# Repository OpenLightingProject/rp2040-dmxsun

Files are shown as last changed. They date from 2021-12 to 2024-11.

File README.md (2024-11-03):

# rp2040-dmxsun: A USB-DMX device based on RaspberryPi's RP2040 micro-controller with modular hardware

<p align="center">

</p>

## What is it?

The rp2040-dmxsun is a multi-purpose DMX-512-A toolbox to control stage lighting systems. It's most common use-case is to transmit the DMX data generated on a PC, Raspberry Pi or similar in a format that the lighting fixtures on stage can understand. In the most simple case, it's an USB-DMX interface.

DMX-512-A works in networks called universes and each universe can contain up to 512 slots of data. dmxsun can transmit up to 16 universes, meaning you can control 8192 slots of DMX data at the same time.

Dmxsun is usually connected to its host via a single USB connection that also powers the device.
To the computer, the dmxsun device looks like a network card (it uses the CDC NCM interface) and the integrated DHCP-server assigns an IP-address to the host machine so they can talk to each other.

To find out dmxsun's IP address, have a look at your kernel log on Linux (run `dmesg`) or hover over the `Disconnect USB device` icon in Window's task bar or check the network device properties on macOS.

You can browse to this IP address in your web browser to access the integrated web server or you can send ArtNet or E1.31/sACN packets to the IP address to make dmxsun send this data as DMX data.

Furthermore, you can attach an nRF24 radio module to the base board to send or receive up to 4 universes wirelessly to or from another dmxsun device. That also means that the device can also work stand-alone, receiving DMX data from another dmxsun device and outputting it on local ports.

## Why is it called dmxsun?

The idea came when thinking about a suitable icon for the pages on the integrated web server. You can think about the dmxsun as being a central device and 16 rays of light coming out of it.

**Sun** could also be seen as an acronym for **s**ixteen **un**iverses :D

Maybe it's also because outdoor lighting technicians absolutely love the sun since they can perfectly set up their light show while the sun is shining bright ;)

## What does it look like?

The hardware consists of a base board into which the Raspberry Pi Pico-board plugs in to. To get a quick overview of the board's status, 8 RGB status LEDs are attached to the base board.

3D rendering of the base board without the Pico board plugged in

Attached to this base board can be 0 to 4 IO boards that carry the actual RS-485 drivers and XLR connectors:

3D rendering of an IO board without the XLR connectors

If all 4 IO boards are attached to the base board, you can have 16 output ports fitting into 1U of an 19" rack:

3D rendering of base board + 4 IO boards

## How is configuration data handled?

The complete configuration of the device, including IP address, patching and wireless configuration can be stored on any of the IO boards or on the base board.

When the device powers up, it scans the 4 IO board slots in order for connected boards and the configuration stored on them. As soon as a valid and non-disabled configuration is found, it is loaded and used. If no IO board has a valid configuration, it tries to load the config from the flash memory of the Pico board. If this also doesn't seem valid, a fallback configuration is applied.

The status LEDs on the base board indicate which IO boards have a valid configuration and which configuration is currently active.

All the configurations can be managed via the integrated web server.

## Where can I buy it?

Short answer: You can't. There is not (yet) a ready-made piece of hardware that can be bought and is ready to use. However, you are invited to build your own. Read on ;)

Longer answer: JLCPCB or a similar PCB factory. The schematics and PCB layout files are in the `hardware` folder (KiCad format) and you can send them to any PCB fab to have it produced for you. Then it's a bit of soldering on your side, plugging in a RaspberryPi Pico board and you're good to go.

If you just want to have a brief look at the schematics without cloning the repo and opening the files in KiCad, take a look at the kicad-export action: https://github.com/OpenLightingProject/rp2040-dmxsun/actions/workflows/kicad-exports.yml. It will generate a zip-archive containing all sort of PDFs.

**!!! Upcoming, incompatible hardware change: In the current schematics, we are using 256 byte large I2C-EEPROMs to store personality and configuration data. With the release of the Pico W and the need to store WiFi SSIDs and passwords, this will no longer be enough and the EEPROMs should provide 4096 byte in the future !!!**

## How can I try it out without spending much?

Very good question! All you need is a RaspberryPi Pico board, a microUSB cable and a PC, Laptop or RaspberryPi. You won't be able to actually control lighting fixtures, but you can get an idea of how this project works.

* Download the latest `UF2`-file (for example from here: https://github.com/OpenLightingProject/rp2040-dmxsun/actions/workflows/pico-build.yml) and flash it to your Pico board (see above)
* Wait until the board has rebooted and your PC has finished setting up the emulated network connection
* Find out the dmxsun's IP address as described in the [What is it?](#what-is-it)-section
* Open your web browser, browse to the IP address. You should see a web page with status information
* Using the navigation bar at the top, browse to `Console` and start changing values. Or fire up your favourite lighting control software (such as OLA or QLC+), configure it to send ArtNet or E1.31/sACN to the dmxsun's IP address and watch the values change in your web browser. It might seem laggy but that's only because the web interface only updates every second.
* If you're curious and have such devices, connect a logic analyzer or RS-485 driver to GPIOs 6 to 21. Those are the pins where the DMX data comes out. If you attach an RS-485-driver to one of those, you can also attach and control real fixtures.

## How do I compile the firmware?

If you just want to get started quickly find the most recent action run from the branch you're interested in, extract the attached artifact zip file (from https://github.com/OpenLightingProject/rp2040-dmxsun/actions/workflows/pico-build.yml ) and copy the rp2040-dmxsun.uf2 file to the Pico board when it's in bootloader mode.

Since this is a project that adheres to the guidelines set by Raspberry Pi for its pico-sdk (hopefully), you are best off following the detailed documentation at https://datasheets.raspberrypi.com/pico/getting-started-with-pico.pdf.

The build process will also build the React App for the integrated Web UI. For this to work, you will need to have NodeJS 14+ and NPM installed. React and all other JavaScript dependencies will be downloaded during the build, so make sure you are connected to the Internet.

With all dependencies installed, the following steps should suffice (example is for Linux, might differ for other OS):
```
git clone --recursive https://github.com/OpenLightingProject/rp2040-dmxsun.git
cd rp2040-dmxsun
mkdir build
cd build
cmake ..
make -j$(($(nproc)+1))
```
This should result in an `.uf2`-file being generated that you can flash to your Pico-board as described in Raspberry Pi's documentation.

**If you are seeing build errors, please make sure you are using pcio-sdk v1.5.0 (released 2023-02-11)**

## How does the data flow internally?

Dmxsun uses a pretty flexible architecture, consisting of mainly 24 DMX buffers acting as the main data storage. Data can come in via USB (either via the emulated Ethernet or some other, emulated protocol), wirelessly via the nRF24 module or from one input port and is then, depending on "patching" stored in one or more DMX buffers.

From there, again depending on "patching", the data is sent to one or more of the local DMX ports, to the nRF24 wireless module or to the host PC via Art-Net or E1.31/sACN.

The patching is currently fixed but will be made fully configurable in the future. The current patching works like this: Universes 1-16 from USB or emulated Ethernet go to internal DMX buffers 1-16 which go to the 16 local DMX ports. Additionally, the first 4 universes are also broadcast via the nRF24 module, should one be connected. Data coming in via the wireless module is sent to DMX buffers 5-8 and will as such appear on the local DMX ports 5-8.

## What are the upcoming features?

The best overview of planned features is to have a look at the GitHub issues: https://github.com/OpenLightingProject/rp2040-dmxsun/issues.

Since the hardware is modular, we do have the option to also support DMX input (currently work-in-progress) or universes with RDM support. There would also be the possibility to drive up to 6 WS2812b-based LED-strings instead of conventional DMX-512-A right off the board.

For the wireless part, mesh support is planned so you can add additional nodes forwarding the data when the wireless range is insufficient. It would also be great if we could talk to other, existing wireless DMX systems.

What might also help to make it easier to use is if dmxsun could emulate other, existing, USB DMX dongles. Then, it could also be used with other software that is not able to send Art-Net or E1.31/sACN but supports other dongles. The disadvantage here is that only a few dongles support more than 4 universes, while dmxsun supports 16.

As said above, the internal patching is hardcoded and cannot be changed by the user. This will change in the future, so that the current patching can be seen and changed in the integrated web interface.

## How is the project licensed?

This source code, schematics and board layouts is licensed under the Apache-2.0 license.

Parts of the original example code (`stdio_usb.*`, ...) is:

     * Copyright (c) 2020 Raspberry Pi (Trading) Ltd.
     * SPDX-License-Identifier: BSD-3-Clause

Parts taken and modified from TinyUSB (`tusb_config.h`, `usb_descriptors.c`) is:

     * The MIT License (MIT)
     * Copyright (c) 2019 Ha Thach (tinyusb.org)

This project proudly uses the following libraries and thanks the respective developers for their amazing work:
* [jsoncpp](https://github.com/open-source-parsers/jsoncpp), MIT license
* [libb64](https://github.com/libb64/libb64), Public domain
* [lwIP](https://savannah.nongnu.org/projects/lwip/), Modified BSD License
* [Pico-DMX](https://github.com/jostlowe/Pico-DMX), BSD 3-Clause "New" or "Revised" License
* [RF24, RF24Network and RF24Mesh](https://github.com/nRF24/RF24), GPL-2.0. Since this is not compatible with our Apache-2.0 license, this dependency will be removed in the future. dmxsun was GPL-licensed in the past
* [snappy](https://github.com/google/snappy), The 3-Clause BSD License

And for the integrated Web UI:
* [React](https://reactjs.org/), MIT license
* [Bootstrap](https://getbootstrap.com/), MIT license
* [Chart.js](https://www.chartjs.org/), MIT license
* [couch64](https://www.npmjs.com/package/couch64), CC-BY-SA
* [snappyjs](https://github.com/zhipeng-jia/snappyjs), MIT license
* [react-input-slider](https://github.com/swiftcarrot/react-input-slider), MIT license

## What else do I need to know?

If you attach an nRF24-board, you yourself are responsible to make sure you don't violate any local laws or regulations. Not all channels and transmit powers that the nRF24 module can use may be allowed to be used in your area. The Open Lighting Project cannot be held responsible should you break the law by using this project's hardware and/or software. Also, we did not run any EMC tests on the hardware. It might not be legal to operate the board without FCC, CE or similar certification, depending on where you live.

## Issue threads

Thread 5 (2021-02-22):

Implement automatic binary generation using GitHub Actions

kripton, 2021-02-22:
The binaries for the Pico board should easily be generated by some kind of CI pipeline

peternewman, 2021-02-22:
Happy to help with this as I've done various similar bits in Actions but doing a GitHub Pages thing to publish may be easier (as the actions artefacts expire after a while and only appear as zips).

I'm assuming RPF have some pretty good docs on it, I guess someone might have made an Action already!

kripton, 2021-02-23:
I am new to GitHub Actions and I was honestly curious to try them out finally :) Didn't find anything on the marketplace and also a quick internet research didn't bring up anything meaningful. Thus, I decided to base off the `cmake` pipeline, add the required steps to set up the Pico toolchain and SDK and off it goes :)
I completely agree that gh-pages might be preferable and now we do have a prebuilt binary in the `bin` folder and the ones generated by Actions from the source. Don't know what's easier for users to find.

peternewman, 2021-02-23:
> I am new to GitHub Actions and I was honestly curious to try them out finally :)

You beat me to it! I got as far as opening a new file on my lunch break then got distracted.

> I completely agree that gh-pages might be preferable and now we do have a prebuilt binary in the `bin` folder and the ones generated by Actions from the source. Don't know what's easier for users to find.

My example may not be hugely helpful as it's somewhat niche, but this uses GH pages (in this case to host a deb):
https://github.com/peternewman/Date-Holidays-GB/compare/actions...peternewman:actions-gh-pages-apt

If you're happy to have the noise in your repo, branches are really easy, there's a commit action. You could link to gh-pages from the readme.

Things to consider:
branch builds - do-able with pages, would just need a bit of thought as to how they're listed to make multiple ones available
PR builds - probably want to be actions only
I think commit scope would be similar in both cases.

Closed 2021-02-23.

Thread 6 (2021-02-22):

Implement a "switch to bootloader" command

kripton, 2021-02-22:
When flashing the Pico over USB (instead of using the SWD-based debug port and OpenOCD), one needs to replug the board everytime it should be flashed. If fhe SDK allows it, add a command to the USB protocol to reboot to the bootloader.

2bndy5, 2021-04-03:
just passing this along:

>If fhe SDK allows it, add a command to the USB protocol to reboot to the bootloader.

It would seem that it does support this. I haven't found any example yet, but I found [_**this macro**_](https://github.com/raspberrypi/pico-sdk/blob/1769968c426555454ab88917115abcb96bcfd1cd/src/rp2_common/pico_stdio_usb/include/pico/stdio_usb.h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) in search of how to redirect UART I/O to USB (or vice versa). I imagine that using this defined baudrate is how the [unofficial ArduinoCore-pico](https://github.com/earlephilhower/arduino-pico) is automatically resetting the board when re-programming the pico (or other RP2040 based boards).

There's also [this library](https://datasheets.raspberrypi.org/pico/raspberry-pi-pico-c-sdk.pdf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) which seems like it would be commonly used by CircuitPython/MicroPython firmware to let the user reset-to-bootloader when the reset button is double clicked.

kripton, 2021-04-20:
Fixed with https://github.com/OpenLightingProject/rp2040-dongle/commit/dd2dc2cf51eed4e9961ec046b7b0a472e5cc146c
@2bndy5: This seems to be some kind of "official" way to do it. It can be enabled in the pico-sdk by adding some #defines to a project, assume it's using the stdio_usb interface. See https://github.com/raspberrypi/pico-sdk/commit/383e88ea165bc63e5755e042608bbc1164e75ab7

kripton, 2022-01-08:
Reboot-to-Bootloader is now also available via the HTTP API (integrated webserver):
https://github.com/OpenLightingProject/rp2040-dongle/blob/79556f4ebf31f9bb41bdc5a23bae965987fad62d/src/webserver.cpp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

Closed 2021-04-20.

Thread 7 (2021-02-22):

Serial Numbers/UIDs

peternewman, 2021-02-22:
I see you've already mentioned this partly in https://github.com/OpenLightingProject/rp2040-dongle/discussions/2 but given it's important we don't get UID clashes in our space so for now if you're using static ones it would be good to switch to some of the reserved ones here (any of the development blocks are fine):
https://wiki.openlighting.org/index.php/Open_Lighting_Allocations#UIDs

What serial(s)/MAC(s) does the RP2040 chip ship with and I can suggest some ways we could make use of them based on what we've done in the past.

kripton, 2021-02-23:
You're right, for now this should be using development IDs.
The RP2040-chip itself has no unique identifier at all. According to RasbperryPi, they are all identical (except tolerances and thus timing differences). However, each Pico board comes with a Flash chip that has a unique identifier (64 bit long). As such, we cannot know if it might clash with the way serial numbers are generated on other boards that use means to generate their serial number.
Sadly, when shorting that flash-unique-id, it's no longer guaranteed to be unique. I was not able to find if there is some kind of meaning to individual bits of the ID (like a common vendor-part).
This is how the unique ID is read from the flash in the pico-sdk: https://github.com/raspberrypi/pico-sdk/commit/620c75b9b85ca160d929a3a5df3c96a8d433f3be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

In the beginning (when the rp2040-dongle was emulating the Nodle U1 board), I had the complete unique ID as a serial number: https://github.com/OpenLightingProject/rp2040-dongle/blob/main/src/usb_descriptors.c#L160 (still current in main branch).
However, since the Ja Rule protocol mandates the PLASA format (which is not a bad thing), those can no longer be used. I've decided to use the last 4 byte of the board id for now: https://github.com/OpenLightingProject/rp2040-dongle/blob/JaRuleProto/src/usb_descriptors.c#L223, not being aware that the OLA-range was already organized that well!

I can't really think of a proper solution since no matter how we shorten, truncate or hash the 8 byte long unique id of the flash, the result will never be guaranteed to be unique, thus they are not safe to protect clashes reliably.

The only thing we could do is to reserve another range (7a70:40000000 - 7a70:4fffffff) and hope they never collide (it's still 28 bit of "randmon-ness", which should suffice in most cases).

peternewman, 2021-02-23:
> You're right, for now this should be using development IDs.

Thanks!

> I can't really think of a proper solution since no matter how we shorten, truncate or hash the 8 byte long unique id of the flash, the result will never be guaranteed to be unique, thus they are not safe to protect clashes reliably.

Agreed, I guess all we can really do is hope no-one is unlucky. OLE also allows a UID value from flash (e.g. for testing collisions or other purposes), so that could be a possible option if someone did have a clash.

> The only thing we could do is to reserve another range (7a70:40000000 - 7a70:4fffffff) and hope they never collide (it's still 28 bit of "randmon-ness", which should suffice in most cases).

For a bit of background see here for more detail of how the OLE UIDs are defined:
https://github.com/OpenLightingProject/ja-rule/blob/0e4bf7bd6e944222f1b64996c93c3ac87a607de5/common/uid_store.c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

If you're never planning to do dummy RDM responders, or responders dummying proxy devices, then you'd only need one UID per device, so could avoid the shift. Although it might be good to keep that an option unless memory space is likely to be too limiting.

I'll have a bit of a ponder, but keeping the potential Microchip OUIs and any future ones sequential and chucking this in at 7a70:e... feels like it might make sense.

peternewman, 2021-02-23:
Random lsusb serial:
E0C912D24340

I don't know if it gives much hint to the numbering, or if it's truly random?

kripton, 2021-02-23:
> > You're right, for now this should be using development IDs.
>
> Thanks!

Implemented in the JaRule-branch: https://github.com/OpenLightingProject/rp2040-dongle/blob/JaRuleProto/src/usb_descriptors.c#L183 and https://github.com/OpenLightingProject/rp2040-dongle/blob/JaRuleProto/src/usb_descriptors.c#L210

> Agreed, I guess all we can really do is hope no-one is unlucky. OLE also allows a UID value from flash (e.g. for testing collisions or other purposes), so that could be a possible option if someone did have a clash.

Yes. At least when I made it that far that I can read & write the flash. Currently, it's the bootloader loading the program and running it. Until now there was no point in storing persistent settings. But yes, I did see the `SET_SERIAL` command in the protocol and thought the same.

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

Indeed, that source code is a good reading. I was not aware that the JaRule devices can act as an RDM proxy and use those 4 bits for that. Nice idea :+1:
And regarding the range, I also had in mind that there should be some space after the current JaRule-ranges in case Microchip acquires more OIDs in the future. I'd be happy with the 7a70:e... range as well :)

kripton, 2021-02-23:
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

That's the one form the bootloader, right? I thought the same at first, however it's not what the both of us thought it was: https://github.com/raspberrypi/pico-examples/issues/6#issuecomment-768149841

What you are seeing there is some kind of revision number of the bootloader and is the same on all Pico boards ;) When the device is running in `BOOTSEL` mode (= bootloader), there is no unique identification feature :-/

peternewman, 2021-02-24:
> Indeed, that source code is a good reading. I was not aware that the JaRule devices can act as an RDM proxy and use those 4 bits for that. Nice idea
> And regarding the range, I also had in mind that there should be some space after the current JaRule-ranges in case Microchip acquires more OIDs in the future. I'd be happy with the 7a70:e... range as well :)

I suspect there's unfortunately not a huge amount of progress likely to be made with Microchip based JaRule stuff, but equally given this is almost pseudo-random UID allocation given the overflow it's probably still sense to split them up.

Are you interested in that level of flexibility in your device?

> That's the one form the bootloader, right? I thought the same at first, however it's not what the both of us thought it was: [raspberrypi/pico-examples#6 (comment)](https://github.com/raspberrypi/pico-examples/issues/6#issuecomment-768149841)

It was some random one off the Internet!

I guess if I load your main branch, I should see my serial there to compare.

kripton, 2021-02-25:
Regarding RDM proxy and the reserved bits, I'm totally unsure. I don't have any experience at all with RDM and cannot judge if the dongle should support that. Sure, with a good number of ports, it could be configured as RDM-capable splitter where this feature would come in handy.
On the other hand, it would increase the likelihood of an ID clash (28 bit of uniqueness vs. 24 bit). I don't have a definite answer but my gut feeling tends to go for 24 bit unique id + 4 "reserved" bits for the advanced RDM functionality. Probably won't hurt.

Indeed, if you flash the current `main` branch (the one emulating the Nodle U1 protocol), you should see the full 8 byte / 64 bit / 16 characters, truly unique serial number.

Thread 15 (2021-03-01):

Simplify Logging Code

peternewman, 2021-03-01:
You've currently got e.g.
https://github.com/OpenLightingProject/rp2040-dongle/blob/08e6e144c32b5bf002fd0e936cf510dbeb2a6162/src/jaruleproto.c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

In OLA we use `__FILE__` too, but we also setup a macro to centralise and tidy most of the back-end commands (although I guess the latter might be a bit harder if it's all in a printf):
https://github.com/OpenLightingProject/ola/blob/ea3a18a925f123c8771ebc6c60327678e99ddcf2/include/ola/Logging.h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

kripton, 2021-03-01:
Indeed, fully agree. That is meant to be a macro eventually. For the moment, it's just written to fulfil the needs.
I did try `__LINE__`, however it contains the full file path and that was a bit long for me. I saw some functions online that return only he filename but I didn't yet bother to integrate them.

peternewman, 2021-03-03:
> I did try `__LINE__`, however it contains the full file path and that was a bit long for me. I saw some functions online that return only he filename but I didn't yet bother to integrate them.

I assume you mean `__FILE__`? That's interesting, in OLA we just get the relative path (say `src/jaruleproto.c`).

kripton, 2021-03-03:
Indeed, I meant `__FILE__`. Maybe it depends on the build system used? It could be that OLA's GNU Make-based build system calls the compiler with relative paths while the CMake-based build system for Pico-projects calls the compiler with absolute paths?

kripton, 2021-03-04:
I played around a little with the logging code. Actually, rather for checking if C++ can be used on the RP2040. Result: Working, but some things (such as iterators) will lead to compile-time errors such as https://github.com/purduesigbots/pros/issues/134

Current status at https://github.com/OpenLightingProject/rp2040-dongle/tree/kripton-cppTest. Can be used as a base but I might rewrite that in plain C. Will see ;)

Closed 2021-12-22.

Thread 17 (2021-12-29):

Any harware refrance.

ScobbyDoo, 2021-12-29:
Hi,
Im looking for any schematic to make one & try
If you have schematic i wll design pcb & share it.

kripton, 2021-12-29:
Hi @ScobbyDoo and I'm happy that you want to try it.
The schematic and PCD design files are in the "hardware" branch: https://github.com/OpenLightingProject/rp2040-dongle/tree/hardware. The files are created using KiCad.
It's basically the baseboard + some baseboard options that you can connect to the base board. I have several ones here, ordered at JLCPCB.

Of course, you can also do a prototyping solution and simply hook up some RS-485-Driver breakout-boards to the RPi Pico board via jumper wires. The connections can be seen in the KiCad-schematics but don't hesitate to ask here if something is unclear.

Each IO board usually contains one I2C-EEPROM to give the base board some information about the IO board (available ports, port direction, .....) but at the moment, the firmware just assumes 16 OUTs

kripton, 2021-12-29:
Oh, and the KiCad-files are automatically rendered to PDFs using GitHub actions. The latest results are here: https://github.com/OpenLightingProject/rp2040-dongle/suites/4741501920/artifacts/130997826

ScobbyDoo, 2022-01-03:
But hiw do i send command to drive dmx?

Is it standalone system ,or usb , Ethernet option available.

kripton, 2022-01-03:
Since I don't know your skill level, regarding DMX-512 hard- and software, it's a bit hard to guess where to start.
If you flash the firmware to an RPi Pico board, it will reboot and start generating valid DMX data right away. However, it's all ZEROs of course. To get it to send meaningful data, you need to connect the Pico-board to some kind of PC via USB. If the firmware is running properly, the Pico board will look to the PC like an Ethernet network card. So it's not real Ethernet but your PC will see a new network card (if your OS is not too old) and will get an IP address from the Pico board via the DHCP protocol. The exact IP that you need to talk to the board differs from board to board (so we can support multiple boards connected to the same PC) but will be in the range of 169.254.XXX.1. You can see the IP if you run `ip addr` on Linux or if you hover the "USB devices" task bar icon on Windows.

Then, you can fire up your favourite web browser and enter the board's IP in the address bar. The web interface of the board should open, showing you the general system status. At the top, there is a item called "Console". If you click there, you will be able to modify the values via the web browser.

The other alternative is to use some kind of DMX-data-generating software such as OLA or QLC+. You can send E1.31 (sACN) or ArtNet frames from that software running on your PC to the Pico board via the virtual Ethernet connection. The Pico board should react to those values and output the data as DMX-512 on one of the GPIOs (depending on universe value in the sACN or ArtNet frames). You should also see the values change on the web interface.

All this can be done without additional hardware. The hardware is only needed if you want to actually connect DMX-512 fixtures, use the wireless modes or want to see the board's status on the status LEDs.

... and I know that I should update the Readme file with all of this information ;)

kripton, 2022-01-03:
So to answer the questions:
It doesn't have a real hardware Ethernet option as of now. Of course, one could attach an SPI or UART-based Ethernet module but it's not yet supported.
It works when connected to a host (PC or RaspberryPi or similar) via USB.
It can also work stand-alone when powered via micro USB connector (power bank or wall-USB power adapter) and when using the wireless module.

ScobbyDoo, 2022-01-05:
Yes, I'm familiar with artnet & e1.31

I will attach Ethernet to controller & send data over udp to mcu ,as per calculation (16 x 512 byte ) universes how do i assign those data to specific data lines

Like store first 512 byte to 1st data line
2nd 512 to 2nd data line
& So on , fill full buffer & driver it on rs485 line

Now the point is how do i fill that buffer & drive it?
I suppose memcpy function may works for that😅

Sorry for silly logics(if their is any)

kripton, 2022-01-07:
Where to you plan to attach the LAN8720a? As I wrote above, the firmware won't recognize or use it. The Ethernet-Emulation uses the USB connection to the host PC. You don't need an Ethernet-cable if you want to send data from your PC to the dongle.

The assignment of the data to the "data lines" is done automatically. In ArtNet and sACN you can specify a "universe id/number". That number is used to decide on which pin the data will be sent/driven. Yes, memcpy is also used in the background but the firmware/code for all that is already done.

To go step by step: Do you have a pico-board connected via USB to your PC with the rp2040-dongle firmware running?

kripton, 2022-01-07:
Oh, and to avoid any mis-understandings: This project is not a library that you should include in you projects. It's a project for a "complete device" on its own. If you simply want to "use it", there's no code that you need to write. Just build/order the hardware and you're good to go.

kripton, 2022-01-08:
@ScobbyDoo : I've prepared a new version of the README: https://github.com/kripton/rp2040-dongle/tree/readme
Check it out and tell me if there's anything unclear :+1:

kripton, 2022-07-07:
For connrcting Ethernet, see #29. Closing this due to inactivity, feel free to reopen

Closed 2022-07-07.

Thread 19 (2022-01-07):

Hardware: Migrate files to KiCad 6.x format

kripton, 2022-01-07:
KiCad v6.x changed the file format, especially for the schematics (see https://www.kicad.org/blog/2021/12/KiCad-6.0.0-Release/). The current files in the `hardware` folder should be migrated to this new data format.
Also, the GitHub-Actions might need to be updated/adapted.

Closed 2022-12-02.

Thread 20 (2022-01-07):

Implement wireless mesh

kripton, 2022-01-07:
Currently, only "sniffer" and "broadcast" wireless modes are implemented. However, the RF24-library also supports a mesh mode (https://nrf24.github.io/RF24Mesh/index.html).This has the great benefit, that packets can hop from one node to another to extend the possible range. In the example topology (see https://nrf24.github.io/RF24Network/md_docs_tuning.html), let's assume the master node "00" is attached to a PC and receives DMX data from there. The nodes "015" and "025" are out of radio range of "00" and cannot directly receive the data. However, node "05" has "00", "015" and "025" in radio range and forwards data from "00" to "015" and "025".

However, the mesh is not "fully automatic" or self-healing. This means that some configuration needs to be done by the end user / operator.

Work in progress at https://github.com/OpenLightingProject/rp2040-dongle/compare/main...kripton:mesh.

To clarify:
* How to implement "true broadcast" with RF24Mesh / RF24Network. "Multicast" between a group of nodes is implemented, but not a "broadcast to all nodes"
* How to keep stats / reachable nodes / mesh topology information available at every node?
* What about many nodes joining and leaving the network. Are the ids "burned" or can they be re-used?

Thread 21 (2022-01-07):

Implement DMX input

kripton, 2022-01-07:
Currently, only DMX output is implemented. However, DMX input is highly desirable (so we can build an active DMX splitter, or receive DMX data from a console on an input port and forward that data to a PC or via wireless) and is also a requirement for RDM.

DMX input on the rp2040 has been implemented at https://github.com/jostlowe/Pico-DMX and I've verified it working (after some changes that have been merged in the meantime).

However, with the current "big locks" (which disable all interrupts as well) in the code, incoming DMX frames could be lost (if the end of an incoming DMX frame happens while the CPU is busy generating data for the next frames to be sent).

So besides changing the patching infrastructure and properly assigning the PIOs, SMs and GPIOs properly, the locking and interrupt disabling code needs to be re-worked.

Proposal: Split up the current "big lock"/spinlock to several smaller ones and think hard, when to disable interrupts and when not. Caution: Deadlocks can appear when code owning a mutex is interrupted by a service handler that also wants the same mutex that is locked by the interrupted code.

Also, the incoming data should NOT be immediately processed in the ISR. It should be appended to some kind of queue and be handled in the main loop.

Work in progress is here: https://github.com/OpenLightingProject/rp2040-dongle/compare/main...kripton:dmxIn

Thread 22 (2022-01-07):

Implement RDM

kripton, 2022-01-07:
Lots of work to be done here :)
Depends on #21

I personally don't have much experience with RDM. I do understand the concept and benefits. However, I don't have any real fixtures to test it, only the "Arduino RDM responder".

peternewman, 2022-01-10:
> Lots of work to be done here :) Depends on #21

You don't need the hard bit of #21 in break detection for RDM, but you will need a lot of other input stuff.

> I personally don't have much experience with RDM. I do understand the concept and benefits. However, I don't have any real fixtures to test it, only the "Arduino RDM responder".

The Arduino responder ( https://github.com/mathertel/DmxSerial2 ) should be fine, I've run the OLA tests against it and keep fixing issues. I can test with some proper gear too if I build myself a real version of this.

kripton, 2022-01-10:
Cool :+1:
We should also re-check what parts of the JaRule-project can be re-used since that does RDM as well

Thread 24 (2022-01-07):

Hardware: Footprint of NC3FD-H is incorrect

kripton, 2022-01-07:
Some IO boards (4ports_unisolated for example) feature the NC3FD-H connector. Since that part was not available in any KiCad-library, I created it myself. However, the drills on the PCB are now smaller than what the actual connector requires and as such the connector cannot be soldered to the PCB :(

kripton, 2022-11-18:
Drilled holes were too small. CAD drawing was correct, I just read the wrong values. Fixed by #57

Closed 2022-12-02.

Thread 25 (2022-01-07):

Hardware: Finish the IOboards with 5-pin XLR connectors

kripton, 2022-01-07:
Currently, only the IOboards with 3-pin XLR connectors are done and have been ordered and tested. The 5-pin variants are not yet completed and/or tested. 5-pin XLR connectors a must to fulfil the actual DMX-512-A specification and for professional users.

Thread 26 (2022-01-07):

Hardware: Finish, order and test the "isolated" IO board variants

kripton, 2022-01-07:
For cost reasons and since I didn't know for sure if all features I had in mind actually work, I only ordered, soldered and tested the "unisolated" variants of the IO boards.
The "isolated" (= galvanically isolated and better protected against ESD) variants are more or less done but are yet untested. They are more expensive since they require DC/DC-converters with quite some output power and the isolated RS-485-driver ICs are more expensive than the non-isolated ones.

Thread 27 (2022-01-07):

Hardware + Software: Create an  "LED-String" board

kripton, 2022-01-07:
This project is mainly focused on generating DMX data and driving RS-485-lines with it. However, due to the modular hardware design, the firmware can also be used to drive LED-pixel-strings with WS2812b or similar protocols.

The current boardconfig-data already has fields prepared for IO boards with that purpose. However, the hardware design and firmware implementation has not yet been done.

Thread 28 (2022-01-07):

Hardware: Design baseboard with fewer slots

kripton, 2022-01-07:
Currently only a "full-blown", 4-slots baseboard has been designed to test the full capability of the hardware. However, most of the time, 16 universes are not needed and a smaller footprint would be desired.

Therefore, we should have:
* A baseboard with only ONE slot for an IO board
* A baseboard with TWO slots for IO boards
* Maybe a 4-slot-baseboard with one IO board to the west, two to the south and one to the east. Will be much more compact than the current layout that is focused on getting 16 XLR-ports fitted into 19", 1 U

kripton, 2022-11-29:
smaller baseboard with 2 slots is in progress

Closed 2022-12-02.

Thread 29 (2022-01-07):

Support for "real" Ethernet hardware

kripton, 2022-01-07:
The current implementation emulates a network device via USB (CDC NCM) so that the host computer can transfer data via IP packets (web interface, ArtNet, E1.31/sACN). However, attaching a real Ethernet device could be beneficial. One could build a standalone 16-port ArtNet-to-DMX adapter.

However, the rp2040 only has a limited amount of GPIO pins and there are probably not enough to cater for a LAN8720 board (except if some of its pins were optional). There might be Ethernet-Boards that attach via I2C (no additional pins required) or SPI (one additional pin required for the CE line).

This will also require quite some refactoring on the software side. We could go all the way to allow packet forwarding from the emulated USB network interface to the "real" Ethernet hardware, so the dongle could be used as USB-to-Ethernet adapter as well. I assume that would not be worth the effort ;)

kripton, 2022-06-16:
Nice, that code example looks pretty useful. I thought the enc28j60 might take some more work and pins to get running but the effort looks manageable. The only pin on the Pico board that is still unused is GPIO 27, so I would plan that as CS line for the ENC chip. However, there is no GPIO left for interrupt, expect if we drop 26's function to trigger scopes at the beginning of a DMX frame. For the nRF24 interrupt there is really no pin left then and right now the code polls the chip if packets have been received. When the SPI bus is shared between the ENC and the nRF24, this might introduce delays. On the other hand, the SPI can run at 10 MHz (at least with the nRF24 only, I didn't check the ENC chip) so that should be fast enough. And even then it would only matter if folks use both Ethernet and wireless at the same time. Also I didn't see the code where the example you linked to defines or uses the interrupt PIN. Might have missed that though.
Yes, lwIP can handle multiple interfaces. The current code has a define set for single-interface mode to save code space, runtime memory and CPU usage but of course one can check if it works having two interfaces, the USB one with fixed IP and the Ethernet with IP from DHCP or fixed as well.
I might have some ENC breakout boards lying around, I will take a look this evening.

kripton, 2022-06-16:
I just looked that up: The ENC28J60's SPI interface supports up to 20MHz, so staying with the current 10MHz should be fine

kripton, 2022-06-16:
Okay, I also found the place where the interrupt Pin is being configured and used: https://github.com/krystiancha/pico-enc28j60/search?q=INT_PIN
Well, we will ise GPIO 26 for that then and now really all GPIOs are in use.
As an alternative, one could add an I2C-attached GPIO chip for the two CS pins and the CE pin of the nRF24. Might make the SPI communication *a bit* slower though

6by9, 2022-06-16:
> Also I didn't see the code where the example you linked to defines or uses the interrupt PIN. Might have missed that though.

https://github.com/krystiancha/pico-enc28j60/blob/master/src/examples/lwip_integration.c#L95

Sharing SPI will have locking issues as your RF24 code is running on core1 whilst enc28j60 is likely to be on core0.

I suspect that having either RF24 or wired ethernet will be more stable, but it's always fun to push the boundaries.

kripton, 2022-06-26:
Okay, first progress report. Also more or less for myself so I can remember what I did, what worked and what didn't.
I found and hooked up an ENC28J60 via SPI to the Pico running the dmxsun software. With the `pico-enc28j60` unchanged and the nRF24-module-code active (although no radio module attached), it didn't work. However, when I modified the enc28j60-code a little (to re-init the SPI before every read and write), the pico started to react to ping-messages :partying_face: . This also worked fine with SPI@20MHz over breadboard-wire and with the logic analyzer attached.
The web server was also working as expected and the WebUI was usable over Ethernet. However, when I started sending ArtNet-frames via QLC+ (one universe only, for now), the WebUI stopped updating and the board stopped sending ping-replies. The interrupt-line between the enc28j60 and the Pico as well as the SPI traffic were still looking normally. When I stopped sending ArtNet-frames, the SPI traffic went back to the previous patterns but the ping-replies were still missing. Needs investigation if it's a (hardware) issue in the enc28j60-board (or maybe an TX overflow) or something that I can fix in software.

Also still on my TODO: Verify that Ethernet works with an nRF24-module also attached to the board. With and without wireless traffic. Additionally, all tests were done with the USB cable of the Pico disconnected (and powered externally), so I never had two net-interfaces UP at the same time in the lwIP-stack.

So, in general the integration of the enc28j60 works, pinout is fine, basic functionality working but quite some work remaining.

kripton, 2022-06-26:
WiP branch: https://github.com/OpenLightingProject/rp2040-dmxsun/compare/main...kripton:ethernet

kripton, 2022-06-27:
Today's achievement: I can successfully receive and process ArtNet via the enc28j60-board. Right now, 4 universes are working fine. However, at some point the emulated network interface via USB stops working. With one or two universes both network interfaces are working. When more data is coming in via Ethernet, the USB network just stops. Might be due to load, might be due to locking issues. I'm honestly thinking to either introduce a proper task/thread management or re-base the whole work to be on top some free RTOS so both cores can be used most efficiently.

Also what doesn't yet work is initializing and using the enc28j60 when the nRF24 module is present. The latter always takes precedence and blocks the ethernet module. I didn't investigate deeper since connecting the nRF24, the enc28j60, a logic analyzer and probably the picoprobe debugger as well requires some more advances wiring here ;)

6by9, 2022-06-30:
https://www.raspberrypi.com/news/raspberry-pi-pico-w-your-6-iot-platform/ would be the other reason I was looking at alternate network hardware with this project.
Sadly time hasn't allowed me to get it working as yet.

@kripton It should be available from the normal suppliers, but if you wanted a couple of samples then drop me an email with your address (dave.stevenson at the same domain as the blog post).

framethespace, 2022-11-10:
Hi, this might be a stupid question, but what are the advantages of an ENC28J60 over the W5500 which seems to be cheaper, more available and has good community support (Arduino and such), again, I might be mistaking :)

6by9, 2022-11-11:
> Hi, this might be a stupid question, but what are the advantages of an ENC28J60 over the W5500 which seems to be cheaper, more available and has good community support (Arduino and such), again, I might be mistaking :)

When I looked at it the W5500 appeared to be doing the TCP/IP side as well, rather than just the base ethernet.
That reduces flexibility if you want to do a non-IP based protocol, is likely to be trickier to integrate alongside lwip, and I wasn't sure whether you could get direct access to the sockets in a tidy manner.

Doing a search now does appear to list some Lwip integrations with W5500, referencing a "MAC RAW" mode, so I may have just missed it.
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
kripton, 2022-11-15:
Oh, and I just found out that JOY-IT (one producer or designer of the USR-ES1 module) advertises the Pico compatibility in its manual: https://www.joy-it.net/files/files/Produkte/SBC-USR-ES1/SBC-USR-ES1_Manual_2021-04-22.pdf

kripton, 2022-11-27:
One issue I thought the W5500 has against the ENC28J60: It doesn't ship with a MAC address, so one would need to officially obtain some. As those need to be worldwide-unique, one would have to buy/register some. However, I just  found out that the ENC28J60 actually also doesn't ship/own a MAC address of its own. So the problem is just the same.
Current solution is a hard-coded MAC address in the code: https://github.com/OpenLightingProject/rp2040-dmxsun/compare/main...kripton:ethernet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

Maybe we could just do as most Desktop Virtualization software does: Have a fixed vendor ID and randomly generate the remaining three bytes. Or use the last three bytes of the Pico's unique ID as the MAC address.

kripton, 2022-11-27:
What would work and would be perfectly legal: https://github.com/openmoko/openmoko-usb-oui/blob/master/ieee_oui.psv

peternewman, 2022-11-27:
> However, I just found out that the ENC28J60 actually also doesn't ship/own a MAC address of its own. So the problem is just the same.

That's a shame, the PIC that Ja-Rule uses has an OUI assigned even if it doesn't have a Phy fitted.

There are suggestions that some of the devices you mention come with a sticker with the MAC set. Although you still need to burn it into the device somehow.

> Maybe we could just do as most Desktop Virtualization software does: Have a fixed vendor ID and randomly generate the remaining three bytes. Or use the last three bytes of the Pico's unique ID as the MAC address.

There's also the local bit:
https://en.wikipedia.org/wiki/MAC_address#Universal_vs._local_(U/L_bit)

> What would work and would be perfectly legal: https://github.com/openmoko/openmoko-usb-oui/blob/master/ieee_oui.psv

Ah cool, and people grab sensible but reasonable ranges so you can have a few on the same network!

If you grab a block you should record them here:
https://wiki.openlighting.org/index.php/Open_Lighting_Allocations#UIDs

And probably also pick a unique development MAC in the range (mapping to one or a range of development UIDs) which the device boots with if no MAC is set.

I assume a non-W Pico doesn't have a MAC? Equally if someone uses a Pico W but not the wireless bit, could you just borrow the MAC from that? I'd imagine most people won't want to use them simultaneously?

kripton, 2022-11-27:
> That's a shame, the PIC that Ja-Rule uses has an OUI assigned even if it doesn't have a Phy fitted.

Indeed. There are modules available that contain an EEPROM with a unique MAC but they are of course more  expensive. Nice that they ship the PICs with a MAC.

> > Maybe we could just do as most Desktop Virtualization software does: Have a fixed vendor ID and randomly generate the remaining three bytes. Or use the last three bytes of the Pico's unique ID as the MAC address.
>
> There's also the local bit: https://en.wikipedia.org/wiki/MAC_address#Universal_vs._local_(U/L_bit)

Yep, I was aware and for the USB-Ethernet-Connection we are using it. I fear that some switches might drop those packages but if it proves to work fine, why not? It would at least guarantee that there is no collision with "globally managed MACs".

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

Would you say it makes sense to request a range? I'm a bit in doubt there since they can of course only give "small" ranges. And that range might not be sufficient to avoid collisions if there are say 32 devices on the same network?

> And probably also pick a unique development MAC in the range (mapping to one or a range of development UIDs) which the device boots with if no MAC is set.

There is a special range for R&D devices at the beginning of their list.

> I assume a non-W Pico doesn't have a MAC? Equally if someone uses a Pico W but not the wireless bit, could you just borrow the MAC from that? I'd imagine most people won't want to use them simultaneously?

Right, the non-W Pico doesn't have a MAC. I would assume it would be safe to re-use the wireless MAC for the eth interface (even if probably not allowed). And I want to see the face of the user that first connects the device via WiFi and Ethernet to the same network :D And I'd rather use the same approach for W and non-W Picos to keep it easy. But sure, the idea is valid :)

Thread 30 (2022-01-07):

Hardware: Add Grove I2C connectors to base board

kripton, 2022-01-07:
The base board already routes the I2C bus to the IO boards. It would be nice if a Grove-compatible connector would allow additional extensions (OLED, LCD, input buttons, NFC?, ...).
Effort should be minimal.

Closed 2022-12-02.

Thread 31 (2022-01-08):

Add optional Grove-compatible connectors to IO boards

kripton, 2022-01-08:
Seeed studio provides an "Grove DMX module" (https://wiki.seeedstudio.com/Grove-DMX512/) which is basically an RS-485-driver + 3-pin XLR connector. It's not cheap, it's not 5-pin and it cannot do input or RDM.
However, we could support it by adding Grove-compatible connectors to the IO boards (before the RS-485 driver).

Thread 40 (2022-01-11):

Re-investigate on zeroconf / mDNS

kripton, 2022-01-11:
Currently, the device chooses one IP address based on the chip ID in the flash memory (if no IP has been stored in the config) and provides another IP in the same subnet to the host machine via DHCP.
This might be easier using AutoIP/APIPA provided by the lwIP stack: https://www.nongnu.org/lwip/2_0_x/group__autoip.html. We just need to make sure that all host OSes we want to support don't treat network connections as non-functional if their DHCP requests go unanswered.
Zeroconf is the name of the technology / processes ifself. Apple Bonjour and Avahi are two widely-known implementations.

Also, usbsun should at least advertise some kind of hostname and the services it provides via mDNS (also already supported by lwIP).

peternewman, 2022-01-12:
I didn't realise the mDNS bit and the standalone IP bit were both part of the same standard!

I think Zeroconf has pretty wide OS support now, although Windows may flag the network as no Internet access.

kripton, 2022-01-12:
Well, it's not necessarily. Sorry if I made that impression. Standalone IPv4 is in https://datatracker.ietf.org/doc/html/rfc3927, mDNS is in https://datatracker.ietf.org/doc/html/rfc6762 and https://datatracker.ietf.org/doc/html/rfc7558

The lwIP usually assumes you are using their AutoIP-feature when you activate their mDNS-feature but at least according to their docs, it's not a must:
`MDNS with IPv4 requires LWIP_IGMP = 1, and preferably LWIP_AUTOIP = 1.` (https://www.nongnu.org/lwip/2_0_x/group__mdns.html). IGMP is already in use for E1.31 multicast to work.

So while I'm still not sure about AutoIP, mDNS makes sense in any case.

And about Windows flagging the network as "No Internet access": That shouldn't be a problem since this is just the truth.

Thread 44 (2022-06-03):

uf2-file

gobo-ws, 2022-06-03:
Hi,
I am struggling to understand GitHub actions but I guess I don't have enough patience at the moment :)

> If you just want to get started quickly find the most recent action run from the branch you're interested in, extract the attached artifact zip file (from https://github.com/OpenLightingProject/rp2040-dongle/actions/workflows/pico-build.yml ) and copy the rp2040-dongle.uf2 file to the Pico board when it's in bootloader mode.

I don't find any zip file or how to generate it?

kripton, 2022-06-04:
True, the results/artifacts are not easy to find if you are not used to it. Try this one: https://github.com/OpenLightingProject/rp2040-dmxsun/suites/6080805161/artifacts/210508458

gobo-ws, 2022-06-04:
Many thanks @kripton

Closed 2022-06-04.

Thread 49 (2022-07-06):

Support Web interface, Art-Net, E1.31 and EDP via WiFi on the Pico W

kripton, 2022-07-06:
Raspberry Pi released the Pico W including on-board WiFi :partying_face: https://www.raspberrypi.com/news/raspberry-pi-pico-w-your-6-iot-platform/

While the radio-module doesn't support narrow-band RF in the 2.4GHz band and Bluetooth is not yet supported/enabled, the new Pico W is pin-compatible (except the on-board LED) with the current one.

It sounds like a good "step up" from the regular Pico and to enhance the dmxsun with the web interface, Art-Net, E1.31 and EDP via the WiFi-interface in addition to the emulated CDC NCM via USB.

Things needing work:
- The on-board-LED is now managed via the radio module. As such, GPIO 25 is no longer available and https://github.com/OpenLightingProject/rp2040-dmxsun/blob/main/src/pins.h#L45 leads to a compilation error. Easy fix
- pico-sdk 1.4.0 seems to ship lwIP in two places: `lib/tinyusb/lib/lwip/` (where it already was before) and `lib/lwip/` (where it was added to support IP via the cyw43 driver. This leads to the following compilation error (might be version conflict, needs investigation):
```
In file included from /opt/raspberrypi/pico-sdk/src/rp2_common/pico_cyw43_arch/cyw43_arch.c:12:
/opt/raspberrypi/pico-sdk/lib/cyw43-driver/src/cyw43.h:118:17: error: field 'dhcp_client' has incomplete type
  118 |     struct dhcp dhcp_client;
      |                 ^~~~~~~~~~~
```
- The cyw43 radio module seems to need two firmware blobs (https://github.com/georgerobotics/cyw43-driver/blob/195dfcc10bb6f379e3dea45147590db2203d3c7b/firmware/43439A0-7.95.49.00.combined, 220kByte and https://github.com/georgerobotics/cyw43-driver/blob/195dfcc10bb6f379e3dea45147590db2203d3c7b/firmware/4343WA1-7.45.98.50.combined, 416kByte). Compared to the 2MByte flash (which is the same since as with the regular Pico and has not been increased for the Pico W), those files are huge. The current main branch of rp2040-dmxsun generates a 1.5MByte uf2-file (debug build), mainly due to the React-based web interface. I'm afraid that with adding the two firmware blobs, the flash memory will not suffice :(. Not yet confirmed since I didn't yet fix the compilation error mentioned above

6by9, 2022-07-07:
```
In file included from /opt/raspberrypi/pico-sdk/src/rp2_common/pico_cyw43_arch/cyw43_arch.c:12:
/opt/raspberrypi/pico-sdk/lib/cyw43-driver/src/cyw43.h:118:17: error: field 'dhcp_client' has incomplete type
  118 |     struct dhcp dhcp_client;
      |                 ^~~~~~~~~~~
```

Most likely unrelated to 2 copies of lwip.
https://github.com/OpenLightingProject/rp2040-dmxsun/blob/main/src/lwipopts.h#L45
```
#define LWIP_DHCP                       0
```
which means that "lwip/dhcp.h" is not included.

Next issue comes up of ```netif_list``` not defined, which is due to https://github.com/OpenLightingProject/rp2040-dmxsun/blob/main/src/lwipopts.h#L75
```
#define LWIP_SINGLE_NETIF               1
```

Link then fails as we have multiple definitions for ```sys_arch_protect```, ``sys_arch_unprotect``` and ```sys_now``` (pico-sdk/src/rp2_common/pico_lwip/nosys.c and rp2040-dmxsun/src/tusb_lwip_glue.c)

6by9, 2022-07-07:
Hacking done and it builds and runs for Pico-W. Branch pushed to https://github.com/6by9/rp2040-dmxsun/tree/pico-w

```
mkdir build
cd build
cmake -DCMAKE_BUILD_TYPE=Debug  -DPICO_BOARD=pico_w -DWIFI_SSID="Your Network" -DWIFI_PASSWORD="Your Password" ../src
make -j4
```

No code written to actually add the wifi side, but the USB network interface still works.
I probably should have based it off your https://github.com/kripton/rp2040-dongle/tree/ethernet branch, but there you go.

kripton, 2022-07-07:
Amazing, nice work! I can confirm that the compilation works and includes the cyw43-driver. However, I don't see the firmware getting included and the resulting uf2-file is still 1.5MByte.
Regarding flash memory consumption, here's the idea to compress the firmware: https://github.com/georgerobotics/cyw43-driver/issues/4

kripton, 2022-07-07:
Correcting my previous comment: That objcopy call wraps the binary firmware in a valid elf object file so it can be linked. Content/format of the input doesn't matter so precompresssed should be fine

kripton, 2023-02-08:
Mostly done with #68. WebUI, ArtNet and sACN work over WiFi when configured properly in the source code.

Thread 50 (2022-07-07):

Use libartnet for Art-Net tx/rx instead of own implementation

kripton, 2022-07-07:
OLP has a generic Art-Net implementation (https://github.com/OpenLightingProject/libartnet). This should probably be preferred to the current "custom" implementation

6by9, 2022-07-19:
I looked at libartnet previously.

It makes a lot of assumptions about being able to access the network stack directly in https://github.com/OpenLightingProject/libartnet/blob/master/artnet/network.c, which doesn't map very well onto lwip or other non-mainline (ie Linux or Win32) platform. Calling ```select``` on an file descriptor is really not going to fly on Pico.

Ideally it wants an abstraction layer for all the network level stuff so that the client can provide the appropriate implementations for eg enumerating interfaces, opening ports, and sending or receiving packets. The default implementation is effectively the current contents of network.c suitably wrapped.

It's also not been touched in 6 years, so is unlikely to support ArtNet4 or other recent additions. I don't know what behaviour you'll get trying multicast over these lower powered network stacks. The chips are unlikely to have significant offload, and whilst lwip has some support for IGMP subscription management, it may not make any significant difference.

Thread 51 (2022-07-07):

Design a "direct GPIO to XLR" board

kripton, 2022-07-07:
See https://github.com/jostlowe/Pico-DMX/issues/27 and https://github.com/kripton/rp2040-dongle/tree/DirectDifferentialOutput: It's possible to directly control fixtures via the GPIOs, not necessarily do we need an RS485 driver. While one cannot drive 16 universes that way (not even 8), it might allow for a very cheap IO board

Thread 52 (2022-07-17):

WebUI: Use websockets instead of http polling/API

kripton, 2022-07-17:
Currently the Web UI uses HTTP call to the device's API to get/update information like device status, buffer content (Console page), log entries, wireless status counters. Usually, a one second update polling interval is being used which makes the Console seem laggy when the values update often or fade. Websockets provide a nice way to make the Web UI more responsive and faster. Some "live audio mixers" that can be controlled via web browser from a tablet or similar uss websockets for control and signal level display (Soundcraft's Ui series).
The client/browser part should not be a problem (and a fallback to polling could be done if the user-agent doesn't support websockets). On the server side (lwIP stack and its http server) impementation will be quite some effort.

kripton, 2022-07-18:
Some references (all seem to implement a custom http server on top of lwIP):
https://github.com/willemwouters/ESP8266/blob/master/projects/apps/websocket_example/src/lwip_websocket.c
https://lujji.github.io/blog/esp-httpd/
https://github.com/maxushka/web_socket_stm32f4/tree/main/Core/Src

peternewman, 2022-08-17:
It would be nice to keep a basic JSON API too if possible if it doesn't add too much codespace, as that's much easier for people just hacking around with the board wanting random integration. Although I appreciate it's probably not the best way to e.g. send DMX data to it.

kripton, 2022-08-17:
Yes, the JSON API is meant to stay, even if websockets are implemented for exactly the reasons you mentioned :)
The "CGI" approach offered by lwIP's web server is a bit awkward and bloats the code a bit but I agree that using curl or wget for simple commands is a big advantage.

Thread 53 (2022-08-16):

DHCP request not acked

cuvoodoo, 2022-08-16:
after the DHCP offer from the RP2040 over USB, the computer (USB host) requests the offered IP.
but the RP2040 does not ACK this request.
thus the DCHP negotiation does not complete and the IP is not assigned to the interface (at least nor under Linuc Arch using dhcpcd).

see attached trace where DHCP client repeats the unanswered request.
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

kripton, 2022-08-16:
Okay, that's strange, works on my machine. Will do a wireshark trace this evening an compare with yours.
In the meantime, is there anything strange in the kernel logs? USB device resetting or similar?

kripton, 2022-08-16:
Just checked, I can definitely see a DHCP ACK here:
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
Did you build the source code yourself or did you use some UF2-file from the GitHub actions?

The DHCP server is part of the lwIP-stack, it's not written by me. I might be able to add or active some debugging options but I didn't yet dig into it.

gobo-ws, 2022-08-17:
I had the same problem with a UF2-file from the GitHub actions (https://github.com/OpenLightingProject/rp2040-dmxsun/suites/6080805161/artifacts/210508458)

kripton, 2022-10-26:
Thanks for the pcap-file, that will help a lot. Unfortunately, I didn't yet find the time to investigate the root cause :/

kripton, 2022-11-01:
I did some investigation today. First thought: Only "a limited amount" of requests can be served. Proofed wrong.
Then I tried `dhcpcd` as DHCP client and I can reproduce the failing behaviour of not getting the `DHCP ACK`. However, when I use NetworkManager's internal DHCP client afterwards on the same connection (= without disconnecting the board), it serves the DHCP ACK just fine. However, still no explanation why this happens. The DHCP server code is not written by me but I will try to debug it to see where it fails.

kripton, 2022-11-01:
I think I found the root cause: tinyUSB's DHCP server expects the MESSAGETYPE option in DISCOVER or REQUEST packages to be the first option in the packet. Some clients seem to not to adhere to this expectations. The trace you attached and the "dhcpcd" I tried send the requested IP option first.

Pull-request for tinyUSB has been created, but it might take some time until the fix makes it into tinyUSB and from there into the pico-sdk. I might try to hack something together so the builds created by the GitHub actions behave correctly.

In the meantime, here's an UF2-file that includes the fix:
[rp2040-dmxsun.zip](https://github.com/OpenLightingProject/rp2040-dmxsun/files/9914443/rp2040-dmxsun.zip). Might be a DEBUG build containing some more logging statements than required but it would be nice if you could confirm that this fixes the issue. Thanks!

kripton, 2022-11-18:
Fix has been merged upstream. I now need to check if I can update to the latest upstream master of tinyUSB or if there are incompatibilities that I need to fix. Thus, leaving this open

kripton, 2023-02-02:
Alright, I'm working on a way to fix this locally without waiting for the upstream version of tinyUSB to tickle down into the pico-sdk.

kripton, 2023-02-08:
Should be fixed with #68.
I copied the DHCP server code into the project to be able to modify it.

Closed 2023-02-08.

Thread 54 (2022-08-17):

slot configuration not completely implementd

cuvoodoo, 2022-08-17:
this is more a status report from trying the project, since the README does not mention it.
currently it is not possible to configure the IO boards on the slots.

`cgi_config_ioBoards_config` in `webserver.cpp` is actually implemented, and is reachable using an HTTP request (such as `http://169.254.59.1/config/ioBoards/config.json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` , values are from `boardconfig.h` ), but the configuration is not reflected back (in the UI or functions).

currently 4 DMX outputs is hard coded and this can't be changed using the config.

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

kripton, 2022-08-17:
Perfectly fine if this is more a status report. Reminds me to add a section about what actually works and what doesn't to the Readme. Thanks :)

`cgi_config_ioBoards_config` is a function that is not necessarily meant to be used by "end users" since it overwrites the "personality" of attached IO boards. The personality is actually given by the hardware, i.e. the type of board. Every IO board has an on-board I2C EEPROM so that the base board can detect it and see what type of board it is. The function you found is to "program" "new" boards that have an empty EEPROM so they know which hardware type they are. (Hint: Current IO boards' EEPROM is small (256 byte if I remember correctly). I plan to use larger ones in the future to be able to store WiFi configuration and other stuff)

The WebUI will only show IO Boards actually present, no matter how you configured them. The "personality" of the IO boards is only stored on them, not on the base board. This makes it possible to have completely different configurations depending in which order you arrange your IO boards..

If you call it without IO board attached (or with nothing at all on the I2C bus), the firmware will try to write an EEPROM that doesn't exist. That should fail but I'm not sure if error reporting is implemented for that function.

If you call it while the IO board is actually connected, it should at least be detected correctly after a board reset. The IO boards are scanned and enumerated as the firmware starts up.

Regarding your "currently 4 DMX outputs is hard coded and this can't be changed using the config": Yes and No. If there are IO boards connected (or more simply: EEPROMs on the I2C bus), they should show up. If the content of the EEPROM tells the base board that it's an "4-input" or an "2-port-IN/OUT/RDM"-board, it should show up as such. However, since at the moment only DMX output is implemented, connecting or emulating any other board than the "4 outputs" won't do much.
DMX input is WIP in this branch: https://github.com/kripton/rp2040-dongle/tree/dmxIn. It's basically working but all the infrastructure around it (support for different IO board types, configuring the PIOs correctly and buffer patching) is still TODO.

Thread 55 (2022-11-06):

Replace kicad-exports with KiCad CI/CD template

kripton, 2022-11-06:
See #35 : kicad-exports has been archived and https://github.com/nerdyscout/KiCAD-CICD-Template is the replacement, so our GitHub action needs to be reworked.

Closed 2022-12-02.

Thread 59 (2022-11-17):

rp2040-dmxsun - system compilation error

trinityworld, 2022-11-17:
window system :-

I am getting complication error when run this command "make -j$(($(nproc)+1)) " and also window has issues finding libraries (lwip)

C:\Users\pico\Downloads\rp2040-dmxsun\pico-sdk\lib\tinyusb\lib\networking\dhserver.h:38:10:
fatal error: lwip/err.h: No such file or directory

i cant find **.uf2** file in this repo. it will be helpful..

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

peternewman, 2022-11-17:
Have you installed the lwip library?

> i cant find **.uf2** file in this repo. it will be helpful..

See https://github.com/OpenLightingProject/rp2040-dmxsun#how-can-i-try-it-out-without-spending-much the artifacts for the run has them.

kripton, 2022-11-17:
The lwIP module is integrated as a submodule and it looks like you didn't clone them. Either run a 'git submodule update --init' or remove your working copy and run the clone again with the '--recursive' parameter

peternewman, 2022-11-17:
> Regarding the UF2 file from the actions: The problem is that they expire and they are only available to logged in users.

You could push them to GitHub pages a bit like I'm doing here if you wanted to offer bleeding edge ones easily for people:

https://github.com/mjemmeson/Date-Holidays-GB/pull/14/files

Although I guess anyone that wants bleeding edge probably has a GitHub account and can grab them...

> I hope GitHub keeps the artefacts when they are linked to a release. Which we don't have yet but will soon.

It does for normal release files, hopefully you can attach them in the same way then.

kripton, 2022-11-17:
Just for reference, latest UF2 is here: https://github.com/OpenLightingProject/rp2040-dmxsun/suites/9370700870/artifacts/441397266

trinityworld, 2022-11-18:
code run successfully and also get **.uf2 file** but webui not generate..

kripton, 2022-11-18:
Okay, that's already some good progress!
Yep, the way the Web-UI compilation is integrated is a bit of a mess (acknowledged as #61). Do you have NodeJS installed? If so, which version and is the "node" command in your %PATH%?

trinityworld, 2022-11-21:
yes, i installed Nodejs.
version is - v18.12.1 and also add "node" command in %PATH%.

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

kripton, 2022-11-29:
Hi, sorry, forgot to reply. Even though you seem to be using Ubuntu by now (#62), I would like to understand why this fails. Most probably since the Web UI is currently built by calling https://github.com/OpenLightingProject/rp2040-dmxsun/blob/main/build-webui.sh. And since there is no bash and some commands in that file will fail on the "Windows command line", this currently just doesn't work. Looks like a limitation of the current solution and tracked by #61.

trinityworld, 2022-11-30:
when i compiled this repo in Ubuntu then web ui generated.now got proper "uf2" file.

@kripton  Thank u so much..

kripton, 2022-11-30:
Glad to hear. You're welcome :) As I said, Linux is only currently supported build environment and it's cool that you managed in the VM!

kripton, 2024-01-05:
Closing as resolved

Closed 2024-01-05.

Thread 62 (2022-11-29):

pico rp2040  and Ethernet hardware configuration

trinityworld, 2022-11-29:
i am trying to Ethernet( ENC28J60 ) configuration with pico rp2040 as per https://github.com/OpenLightingProject/rp2040-dmxsun/compare/main...kripton:ethernet) but get error..

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

kripton, 2022-11-29:
Thanks for the report. In my repo, I can see that file located at `lib/lwip/contrib/apps/tcpecho_raw/tcpecho_raw.h`. Can you confirm this in your local copy?
If not, can you please cd into the directory `lib/lwip`, run `git describe` and show us its output? For me it is showing `STABLE-2_1_0_RELEASE-522-g88ce4385`

trinityworld, 2022-11-30:
> Besides, do you have any specific reason to use the ENC28J60? I'm currently re-designing the PCBs and I would switch to the WZ5500 chip since there are modules available which are cheaper and easier to integrate. If there are no objections or things that the ENC28J60 can do better.

- No reason , just want to drive with Ethernet & this repository already working on it
-  W5500 > yes, i also recommend this module (they have internal ip stack )
-  If you have any documents with w5500(schematic,workflow,firmware) i will work on that & add pull request
-  should i try this board (as 6 to 21 Gpio is used for 16 parallel output) for SPI need bitbang or some other trick

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

**- if not > what will pin connection with Ethernet module (0 to 5 Gpio)**

trinityworld, 2022-11-30:
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

i remove this line " #include "tcpecho_raw.h" from "lwip_integration.c" file as per above mention repository then my previous error  solved.
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

but here,
lwip/../../http/fs.c

library error occurred.

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

trinityworld, 2022-11-30:
why not add  this ->> "lwip_integration.c" file in add_executable list CMakeLists.txt ?..

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

kripton, 2022-11-30:
>     * No reason , just want to drive with Ethernet & this repository already working on it

Well, yes. The ` ethernet` branch is really work-in-progress, it's nothing production-ready. Also the Pico got stuck whan a lot of traffic was created (Denial-of-service :()

>     * W5500 > yes, i also recommend this module (they have internal ip stack )

I know that they have an internal stack but I don't plan to use it. I'd rather keep the software generic to not depend on a specific chip model

>     * If you have any documents with w5500(schematic,workflow,firmware) i will work on that & add pull request

The W5500 (the WIZ850io module to be exact) is added in this branch: https://github.com/kripton/rp2040-dmxsun/tree/kicadUpdates. The baseboard_4slots has a socket for the module and the IRQ line is shared with the nRF24 module. For the new baseboard_2lots, there is a jumper and configurable IRQ pins since less are used for the DMX output. PDFs of schematic and board are available via the actions: https://github.com/kripton/rp2040-dmxsun/actions/runs/3578552144

>     * should i try this board (as 6 to 21 Gpio is used for 16 parallel output) for SPI need bitbang or some other trick

Yes, 6 to 21 are used for DMX output. However, SPI is used to communicate with the nRF24 and I shared this SPI with the WIZ850io. Thus, only one additional CHIP-SELECT pin is required (and the former debug trigger PIN is used as shared IRQ).

> **- if not > what will pin connection with Ethernet module (0 to 5 Gpio)**

Yes, I've seen that module. Unfortunately, the pinout seems to be incompatible with what I've chosen for the dmxsun

kripton, 2022-11-30:
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

It all looks to me like the lwip submodule doesn't match what the other files are expecting. Please see my request from above to show us the output of `git describe` in the `lib/lwip` directory. You can also try running `git submodule update` after you checked out the `ethernet` branch. This should bring the lwip submodule to the correct revision.
In the meantime, I will try with a fresh clone in a clean environment.

kripton, 2022-11-30:
> why not add this ->> "lwip_integration.c" file in add_executable list CMakeLists.txt ?..

Because usually, one links in / references the CMakeLists file from all libraries and the libraries should add the files to be compiled by themselves.

I've just tried compiling this from scratch. On my RPi4 it fails, but with another error and the reason is that gcc 8.3 is the latest version available and that doesn't support C++20, which is required for `src/webserver.cpp`. On my development machine, the `ethernet` branch still compiles fine and creates the .uf2-file.

trinityworld, 2022-12-01:
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

trinityworld, 2022-12-02:
can you please check where is my mistake for assign spi and INT_PIN PIN..

1>lib/pico-enc28j60/enc28j60_lwip_glue.c

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

2> lib/pico-enc28j60/enc28j60_lwip_glue.h
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

3>src/lwip_integration.c

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

4>src/pin.h

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

5>src/main.c

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

trinityworld, 2022-12-05:
here, i get .uf2 file but ..

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

when i ping this static IP address.

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

"Destination Host Unreachable"  error generate

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

trinityworld, 2022-12-19:
pico RP2040 Ethernet branch build successfully..

kripton, 2022-12-19:
Oh nice, tbis is good to hear. Do you mind sharing some insights whaf fixed it for you?

kripton, 2022-12-28:
@trinityworld do you want to tell us what was wrong or how you fixed it? Otherwise I would close this issue.

trinityworld, 2023-01-06:
GPIO 27 use for ENC-INT pin then problem solved..

now i am build project only get 16 parallel output.

https://github.com/trinityworld/pico_dmx/blob/b34064bc0b26339a80139178447e03a13bfb78d1/src/main.c#L102

trying to fill wavetable buffer from 16 universe data (buffer)and after than buffer transfer to 16 gpio as parallel.but here  :(  not get dmx output.

kripton, 2023-01-06:
Okay, I never used the ENC's INT pin on the dmxsun

And I'm getting a HTTP 404 when I try to access your link

trinityworld, 2023-01-09:
https://github.com/trinityworld/pico_dmx/blob/b34064bc0b26339a80139178447e03a13bfb78d1/src/main.c#L102

kripton, 2024-01-05:
@trinityworld : I'd propose to close this issue since it's mainly about the ENC28J60 which will not be used for the dmxsun. I will rather go with the W5500. If you want to keep the support in your fork and it doesn't conflict with other parts, I will gladly accept a PR.

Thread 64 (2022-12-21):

pico only blinks

jazzvivi2, 2022-12-21:
Hello, I'm trying to test your project but I load the latest version of your software and my pico only flashes the led quickly but no network device appears. load some sample uf2 projects and it works. im very new with pico am i forgetting something?

thank you!

kripton, 2022-12-21:
Hi @jazzvivi2 : It depends on how fast the LED blinks. If it blinks VERY FAST (~5-10 times per second), it hasn't yet finished initialization and won't do anything useful. If it blinks slower (~1-2 times per second), it should enumerate as USB device and should be ready to use.

Did you compile the UF2 yourself or did you use one from the GitHub actions?
Which host system (OS) are you using to connect your Pico?
Any hardware attached to the Pico board?

jazzvivi2, 2022-12-21:
Hi @kripton Thanks for answering, the blinking is very fast, the led hardly has time to turn off. I'm using GitHub actions file I did tests on windows and osx and I don't have anything connected to my pico board

kripton, 2022-12-21:
Can you give me the link to the action you took the UF2 file from? I will try to run that here on my Picos. The only thing that I can imagine right now is that your Pico is not able to handle the frequency the firmware configures the cores to: https://github.com/OpenLightingProject/rp2040-dmxsun/blob/main/src/main.cpp#L99. I can build you an UF2 tomorrow that doesn't overclock. Or at least to a lower frequency.

jazzvivi2, 2022-12-21:
https://github.com/OpenLightingProject/rp2040-dmxsun/suites/9865571969/artifacts/475895047

Thanks for everything

kripton, 2022-12-21:
I've tested that UF2 file on three of my Picos. They all behave "good" (= LED blinks very fast for about a second but then changes to the slower blinking pattern).

Here's the variant without overclocking (as soon as the build finishes): https://github.com/kripton/rp2040-dmxsun/actions/runs/3753562092

Do you have another Pico that you could try? Maybe the one that you have was a bit unlucky regarding the process parameters and the cores cannot be overclocked that much?

jazzvivi2, 2022-12-21:
Yes now!! You were right, the problem is speed.
my motherboard is a chinese version (purple with 16mb)
https://es.aliexpress.com/item/1005003260584517.html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

I'm going to play with this and I'll tell you
thank you very much again

kripton, 2022-12-21:
Oh, cool that it worked!
If it's from aliexpress, it's most probably not a "Pico", at least not an original one ;)
And I assume it's the flash that is not able to keep up with the faster clocks. If the SYS clock is made faste, this affects the flash clock as well and in the youtube-video mentioned in main.c, it's also the flash that quits at some point. One could modify the 2nd stage bootloader to clock the flash slower and have the cores still at 250 MHz but probably not worth the effort.
At least good to know that some 16MB flashes cannot do with sysclk at 250MHz!

kripton, 2022-12-21:
It's also interesting that the pin-layout on the edges is different compared to the original Pico

jazzvivi2, 2022-12-21:
you know... aliexpress is always fake. sometimes they improve the designs and many others annoy them. tomorrow I will try to connect an rs485 module and a w5500

kripton, 2022-12-22:
Nice :) You know that the code to get the W5500 working has not even been started? ;)

kripton, 2022-12-22:
Closing this since we found the root cause and workaround

jazzvivi2, 2022-12-26:
hello kripton, first of all congratulations on the holidays. to get dmx output am i supposed to just connect a tll-rs485 module? not having an eprom the board is not recognized. the led of my rs485 board stays on and does not blink like when I receive data

kripton, 2022-12-27:
Indeed, at the moment the EEPROMs don't matter much, the DMX signals generated anyways. Hooking up an RS-485 driver should be enough. Make sure you have the DE and !RE wired properly.
Which LED do you mean?

jazzvivi2, 2022-12-27:
Hello @kripton !

I normally use these boards

https://es.aliexpress.com/item/1005001621746811.html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

they do not have a "de" or "re" pin
Both the input and the output are activated.

If you look closely, this board includes two LEDs, these blink when they receive or send data, in my case it stays on permanently when I connect gpio. I tried all of them and I can't get an output. in the console if I can see the values   that it sends for example qlc+

kripton, 2022-12-28:
very hard to diagnose without access to your hardware. Having the LED constantly lit is not necessarily a bad thing, it could be blinking so fast that your eyes csnnot see that it's actually blinking.
Do you something like an oscilloscope or logic analyzer available that you can connect to the GPIOs to see what they are outputting?

Closed 2022-12-22.

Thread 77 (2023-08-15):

No new .uf2 build last 5 months

ultraw3ird, 2023-08-15:
Currently there is no way to get compiled .uf2 file from this Github. Would it be possible to check bot for automatic builds as all artifacts are long expired? It is pain in the *** to compile it on Windows and not all guys has dedicated linux machine for such a purporse. Thanks in advance

peternewman, 2023-08-15:
Hi @ultraw3ird

I've opened #78 which should also kick off it's own build.

The artefact should be here:
https://github.com/OpenLightingProject/rp2040-dmxsun/actions/runs/5867409629

@kripton we should really publish nightly builds to a GitHub Pages website or something too...

peternewman, 2023-08-15:
Doing formal releases with attached builds would make sense too and could probably be done mostly automagically:
https://github.com/OpenLightingProject/rp2040-dmxsun/releases

kripton, 2023-08-16:
@ultraw3ird : Sorry that no UF2 was available since there was not much progress on this project. Also thanks for the praise that it's nice HW and SW. Did you order & assemble the hardware?
I agree that having an official release would make sense. It's just that I have too much on the ToDo that I'd like to have in the "first release" and I'm pretty bad at "descoping" features so that we could we release with what we currently have ... :/

Closed 2023-08-16.

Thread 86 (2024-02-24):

Supported protocol

godinotomas, 2024-02-24:
Hello,

I want to know whether the project supports WS2812 LEDs and XLights software.

Thank you in advance!

kripton, 2024-02-24:
Hi @godinotomas. I don't know which protocol XLights supports. If it's able to generate ArtNet or sACN, it should work with the dmxsun.
Support for WS2812 LEDs is not yet implemented. It is possible with the hardware and tracked at https://github.com/OpenLightingProject/rp2040-dmxsun/issues/27. If anyone wants a go, PRs are welcome!

How many LED strings would you need? Are 6 enough or would 16 be more interesting?

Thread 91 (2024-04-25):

Device Descriptor Request Failed (RP2040 Zero)

VocasoGK, 2024-04-25:
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

That's what I get when I finished uploading the uf2 file into my RP2040 Zero. There's a notification that says the USB device is malfunctioning. Don't know whether this is a Windows 11 issue, or RP2040 Zero issue. I've tried changing USB ports but the error is still there.

My system is on Win 11 Home (build 22631), AMD Ryzen 5 5600H

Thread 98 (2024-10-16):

Issues with W5500 Branch

BastelPichi, 2024-10-16:
First off, thanks for this awesome project! This project has really gone a long way and looks very promising.

USB works fine, full 16 universes no problemo. However, when using the W5500 branch from your repo, Im not very successful. Ive wired up the W5500, and Ive confirmed it works with another project: [mongoose](https://github.com/cesanta/mongoose).

The code always gets stuck here:
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

The "Link UP detected" also doesnt work, when unplugging and plugging the cable back in. It doesnt really matter if I boot with, or without the LAN cable plugged in.

The module is connected via a switch to my PC and router. When unplugging the uplink from the switch, and capturing traffic with wireshark, and starting the Pico with W5500, nothing really happens. However the Link LEDs do blink periodically.

Ive tried DHCP both with, and without fallback, and neither works.

Do you have any idea? Am I missing something? This happens both with GH Actions build and a build on my PC.

BastelPichi, 2024-10-22:
Ive made progress; having issues with DHCP now, after the server offers an DHCP lease, the pico just stops responding.

kripton, 2024-10-26:
Hey @BastelPichi ,
indeed, the W5500 branch is very experimental and not working as hoped, yet. I started work on it back in the days but meanwhile I got the W5500 working in another project. I need to backport the changes done there to the branch here sometime.
You mean the DHCP client of the dmxsun is not working / correctly parsing the DHCP server's OFFER?

BastelPichi, 2024-10-27:
> You mean the DHCP client of the dmxsun is not working / correctly parsing the DHCP server's OFFER?

Exactly. The Pico receives an offer, then nothing happens. It keeps retrying, USB keeps working. Also not having any success with static IP (Neither ping nor receiving artnet). As far as I have seen, shouldnt all of the DHCP Client stuff done by lwip directly?

I was looking at the Wiznet Library for their Pico W5500 board. If you change the pin config its compatible with the current pin layout, and that might be more future-proof than using the 5 year old W5500MacRaw library.

The inital issue I had with the WIZOK:1, was solved by adding a small delay at startup. Not sure exactly why, but it solved the issue.

Im interested in contributing to this awesome project, is there any chance I can contact you on Discord or IRC?

BastelPichi, 2024-10-27:
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

For reference.

kripton, 2024-11-02:
This is getting interesting. You found the branch in my personal fork but reported the issue here. Nice :) Took me some time to realize.

Can you try setting `LWIP_NETIF_HOSTNAME` to `0` in https://github.com/kripton/rp2040-dmxsun/blob/ethernet_w5500/src/lwipopts.h#L48? If something leads to compilation failures, just surround it with an `#if LWIP_NETIF_HOSTNAME`

I first thought this could be related to https://github.com/hathach/tinyusb/pull/1712 but that was on the DHCP server side, not the client.

Cool that you want to contribute! It's been a long time that I was on IRC the last time but I could start that again. Discord also would be an option. In any case, you can also send me an email. That would not require setting up a time slot ;)

BastelPichi, 2024-11-02:
> Can you try setting `LWIP_NETIF_HOSTNAME` to `0` in https://github.com/kripton/rp2040-dmxsun/blob/ethernet_w5500/src/lwipopts.h#L48? If something leads to compilation failures, just surround it with an `#if LWIP_NETIF_HOSTNAME`
That doesnt change anything. Ive enabled logging:
`dhcp_timeout(): restarting discovery
dhcp_discover()
transaction id xid(775b85a4)
dhcp_discover: making request
dhcp_discover: sendto(DISCOVER, IP_ADDR_BROADCAST, LWIP_IANA_PORT_DHCP_SERVER)
dhcp_discover: deleting()
dhcp_discover: SELECTING
dhcp_discover(): set request timeout 8000 msecs
`
That would explain that. Communication between the module and the Pico defently works (it sends out the broadcast frames afterall).

kripton, 2024-11-03:
Are you using the boards from the "hardware" folder or do you custom hardware / wiring?
Since you said static IP is not working as well: To me it looks like the IRQ line is not working properly. Other projects/libs using the W5500 can do without ([Adafruit's library for example](https://github.com/arduino-libraries/Ethernet) for example).
Initialization will work fine without the IRQ and probably packet sending as well, however packet reception WILL fail. Looks like what you are experiencing.

In case you are using the baseboard from the hardware folder, there is a solder bridge close to the W5500 that selects if the IRQ line (there is only one to the Pico since I ran out of pins) is routed to the nRF24 or the W5500. If you do not solder that to the W5500, it might cause such issues.

The mongoose projects looks very interesting! I was aware that it exists as an webserver-as-a-library but I was not aware that they provide a complete TCP/UDP stack including a W5500 driver. It might be worth investigating if it can replace lwIP completely. Benefits would be a webserver with a less-limited API and with websocket support. However, it would need to handle multiple network interfaces (USB to host, Ethernet via W5500 plus optional WiFi on the Pico W) and we would need to replaces lwIP's fsdata approach.

BastelPichi, 2024-11-03:
> Are you using the boards from the "hardware" folder or do you custom hardware / wiring?
Im using my custom wiring for now.

> Initialization will work fine without the IRQ and probably packet sending as well, however packet reception WILL fail. Looks like what you are experiencing.
The IRQ Callback does get called. So I dont think that is the issue.
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

kripton, 2024-11-04:
Root cause found: eth_w5500 defines a method called `service_traffic` but it is never called. Add it to webserver.cpp in the `cyclicTask()` method. On my desk, it fixes the DHCP client. However, the W5500 link detection behaves flaky and it reports a missing and then a re-established link VERY fast. Not stable here, yet :/

kripton, 2024-11-04:
I did some more playing around yesterday. The wireless code needs to be disabled as well since they share the SPI bus but the W5500 and the nRF are controlled by different cores. Nevertheless, something seems very flaky and unstable.

BastelPichi, 2024-11-04:
I should have the wireless (nrf) disabled, im not really interested in that feature anyways. (Wifi would be nice tho, dont have a Pico W here yet)

The link detection didnt really work at all for me. I can try this later.

However I do need to look into the interrupts, from my understanding the handletraffic only reads out the traffic manually after a 100msec timeout.

Also dont we need to use the MacRaw branch with Pico support? I dont see switching to that branch in your git submodules.

kripton, 2024-11-10:
Yeah, that behaviour is exactly what I meant with "However, the W5500 link detection behaves flaky and it reports a missing and then a re-established link VERY fast.". The W5500 reports an Ethernet link -> DHCP client is started and sends a DISOVER. Then, W5500 reports no link -> if goes down. The, W5500 reports a link again and this leads to the huge amount of DISCOVER packages you see there.
You can watch the whole process in the logs on the emulated serial port if you do not want to rely on (emulated) Ethernet to fetch them.

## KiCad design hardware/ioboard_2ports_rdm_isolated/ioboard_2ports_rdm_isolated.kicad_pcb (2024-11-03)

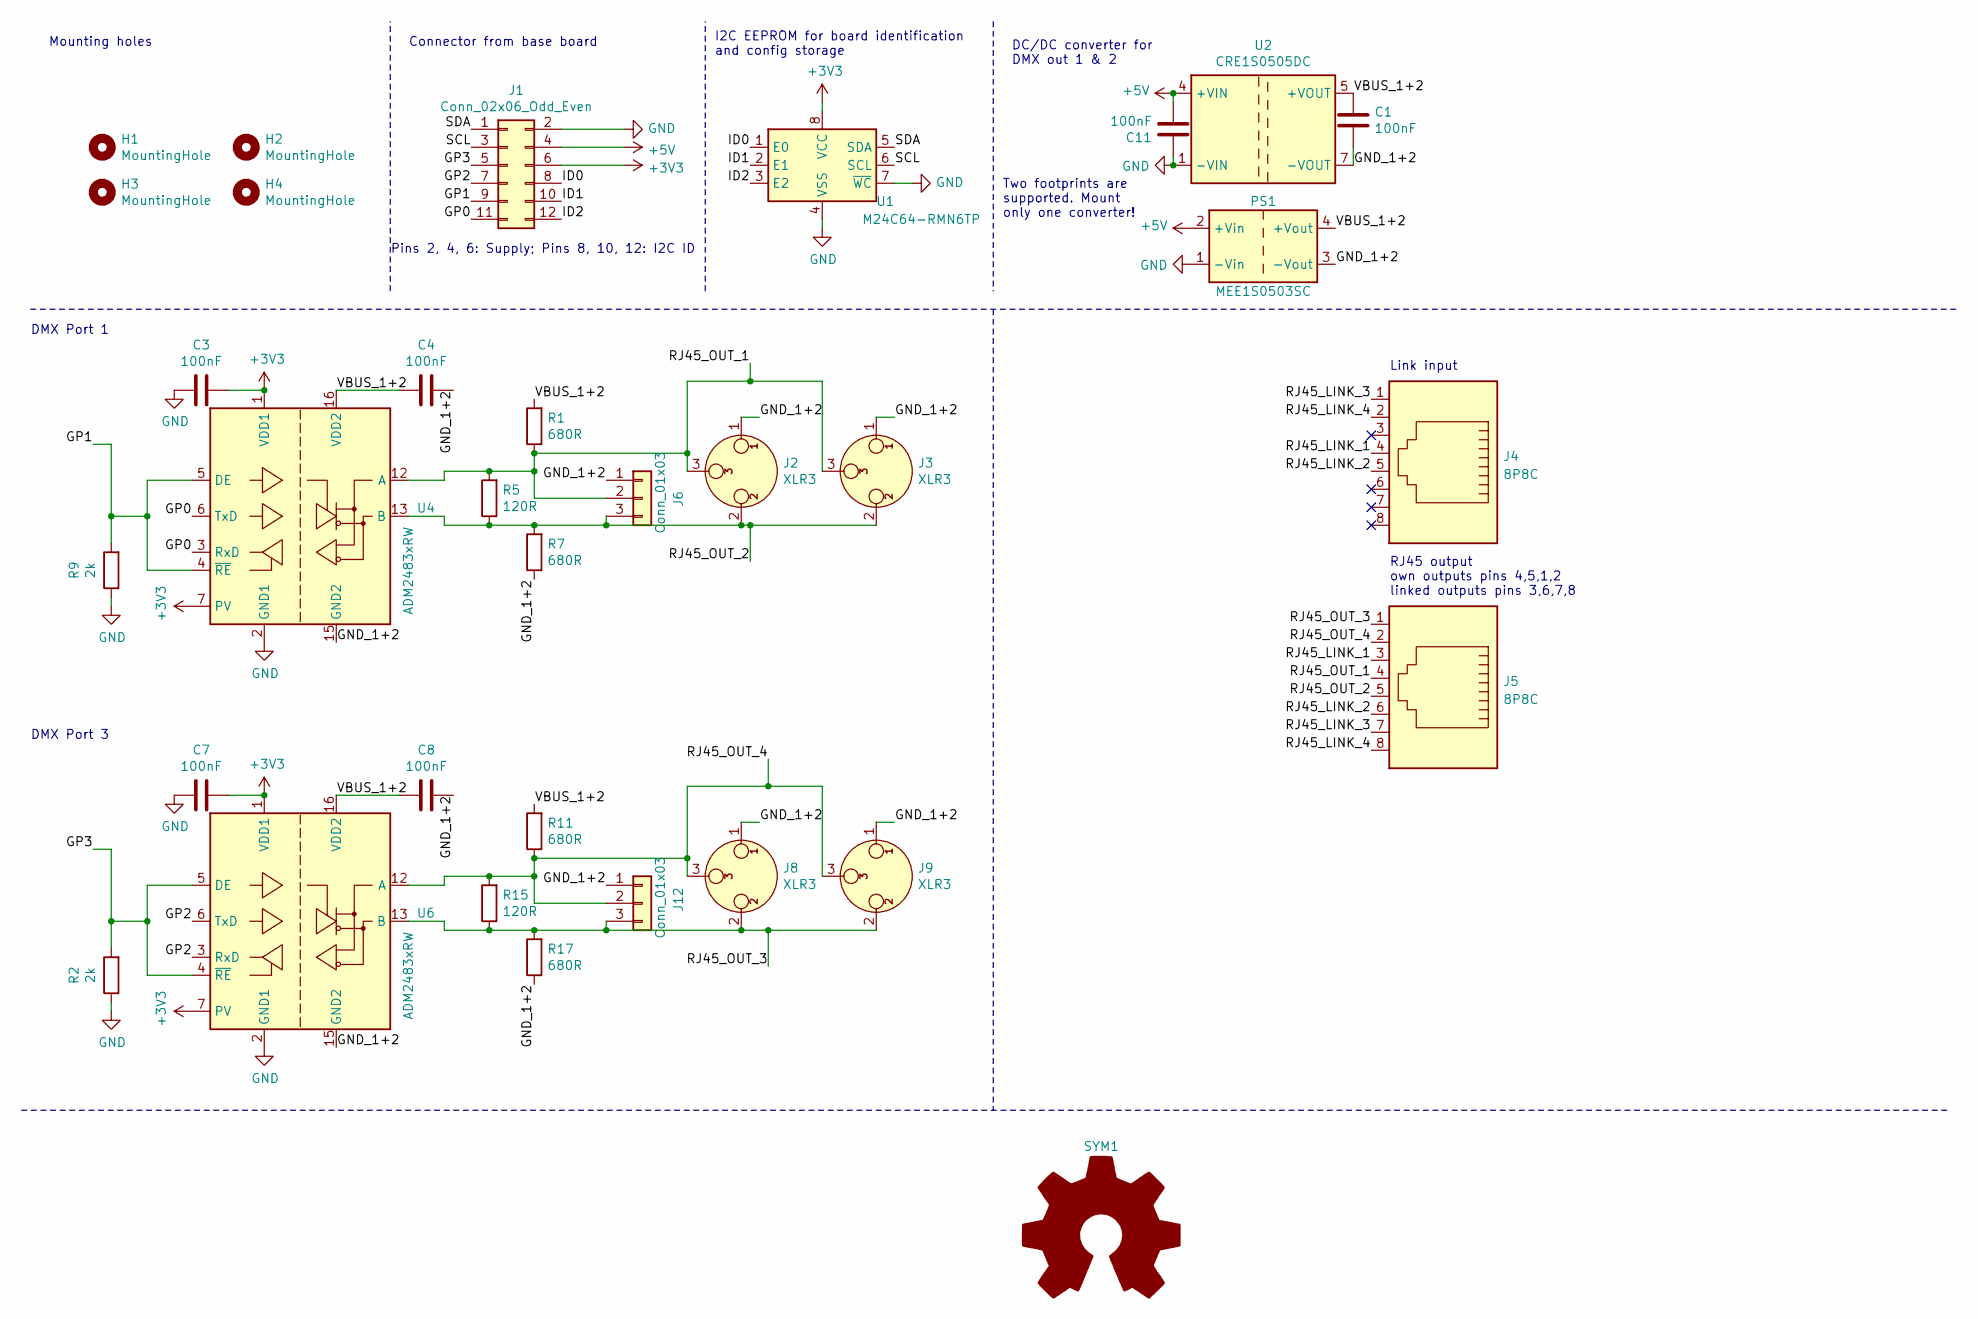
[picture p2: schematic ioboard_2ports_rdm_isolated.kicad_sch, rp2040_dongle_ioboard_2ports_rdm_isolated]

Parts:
C1, C3, C4, C7, C8, C11: 100nF; C_0603_1608Metric; LCSC C14663
H1, H2, H3, H4: MountingHole; MountingHole_3.2mm_M3
J1: Conn_02x06_Odd_Even; PinHeader_2x06_P2.54mm_Vertical
J2, J8: XLR3; Jack_XLR_Neutrik_NC3FAAH_Horizontal
J3, J9: XLR3; Jack_XLR_Neutrik_NC3FD-H_Horizontal
J4, J5: 8P8C; RJ45_Sparkfun
J6, J12: Conn_01x03; PinHeader_1x03_P2.54mm_Vertical
PS1: MEE1S0503SC; Converter_DCDC_Murata_CRE1xxxxxx3C_THT
R1, R7, R11, R17: 680R; R_0603_1608Metric_Pad0.98x0.95mm_HandSolder; LCSC C23228
R2, R9: 2k; R_0805_2012Metric_Pad1.20x1.40mm_HandSolder; LCSC C17604
R5, R15: 120R; R_0603_1608Metric_Pad0.98x0.95mm_HandSolder; LCSC C22787
SYM1: Logo_Open_Hardware_Large; OSHW-Logo2_14.6x12mm_SilkScreen
U1: M24C64-RMN6TP; SOIC-8_3.9x4.9mm_P1.27mm; LCSC C79988
U2: CRE1S0505DC; Converter_DCDC_Murata_CRE1xxxxxxDC_THT
U4, U6: ADM2483xRW; SOIC-16W_7.5x10.3mm_P1.27mm; LCSC C9637

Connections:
+3V3: C3.1, C7.1, J1.6, U1.8 (VCC), U4.1 (VDD1), U4.7 (PV), U6.1 (VDD1), U6.7 (PV)
+5V: C11.1, J1.4, PS1.2 (+Vin), U2.4 (+VIN)
/GND_1+2: C1.1, C4.1, C8.1, J2.1, J3.1, J6.1, J8.1, J9.1, J12.1, PS1.3 (-Vout), R7.1, R17.1, U2.7 (-VOUT), U4.9 (GND2), U4.15 (GND2), U6.9 (GND2), U6.15 (GND2)
/GP0: J1.11, U4.3 (RxD), U4.6 (TxD)
/GP1: J1.9, R9.2, U4.4 (~RE), U4.5 (DE)
/GP2: J1.7, U6.3 (RxD), U6.6 (TxD)
/GP3: J1.5, R2.2, U6.4 (~RE), U6.5 (DE)
/ID0: J1.8, U1.1 (E0)
/ID1: J1.10, U1.2 (E1)
/ID2: J1.12, U1.3 (E2)
/RJ45_LINK_1: J4.4, J5.3
/RJ45_LINK_2: J4.5, J5.6
/RJ45_LINK_3: J4.1, J5.7
/RJ45_LINK_4: J4.2, J5.8
/RJ45_OUT_1: J2.3, J3.3, J5.4, J6.2, R1.1, R5.2, U4.12 (A)
/RJ45_OUT_2: J2.2, J3.2, J5.5, J6.3, R5.1, R7.2, U4.13 (B)
/RJ45_OUT_3: J5.1, J8.2, J9.2, J12.3, R15.1, R17.2, U6.13 (B)
/RJ45_OUT_4: J5.2, J8.3, J9.3, J12.2, R11.1, R15.2, U6.12 (A)
/SCL: J1.3, U1.6 (SCL)
/SDA: J1.1, U1.5 (SDA)
/VBUS_1+2: C1.2, C4.2, C8.2, PS1.4 (+Vout), R1.2, R11.2, U2.5 (+VOUT), U4.16 (VDD2), U6.16 (VDD2)
GND: C3.2, C7.2, C11.2, J1.2, PS1.1 (-Vin), R2.1, R9.1, U1.4 (VSS), U1.7 (~WC), U2.1 (-VIN), U4.2 (GND1), U4.8 (GND1), U6.2 (GND1), U6.8 (GND1)

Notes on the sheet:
I2C EEPROM for board identification and config storage
DC/DC converter for DMX out 1 & 2
DMX Port 3
DMX Port 1
Pins 2, 4, 6: Supply; Pins 8, 10, 12: I2C ID
Connector from base board
Mounting holes
Link input
RJ45 output own outputs pins 4,5,1,2 linked outputs pins 3,6,7,8
Two footprints are supported. Mount only one converter!

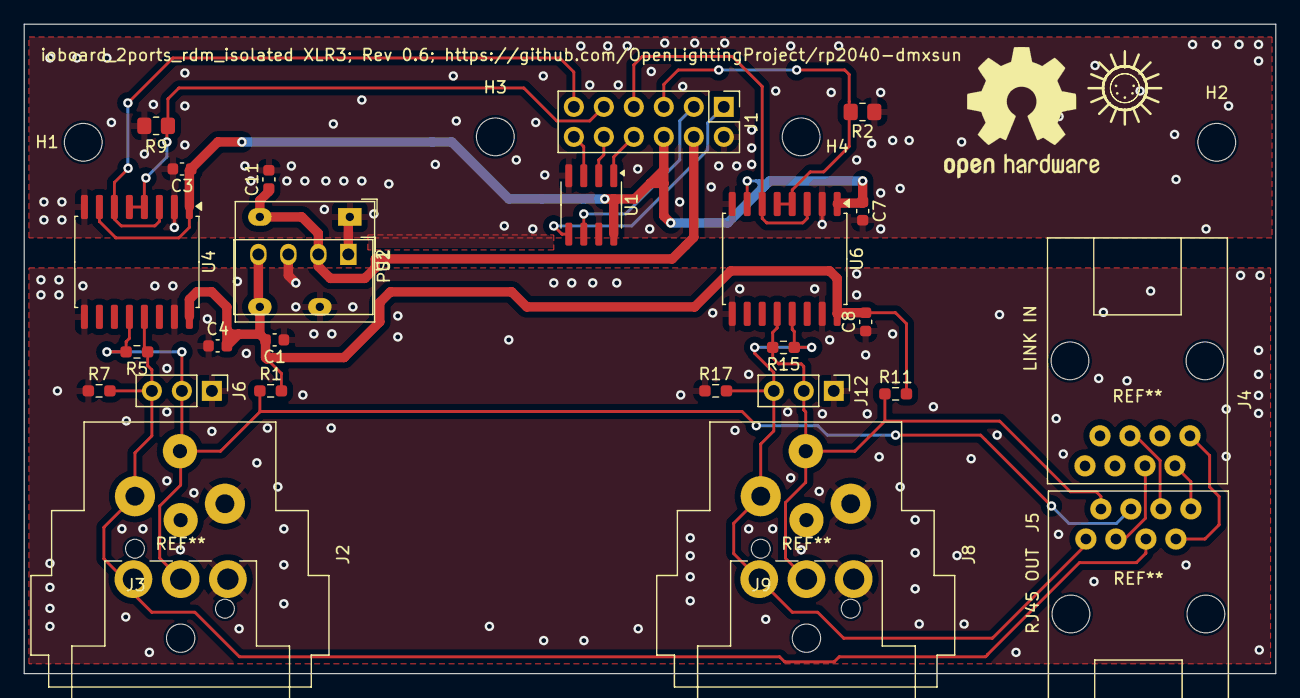
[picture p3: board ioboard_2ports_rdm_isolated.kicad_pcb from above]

Board: 2 copper layers, 106.0 x 55.0 mm, 33 parts (0 on the bottom side), 22 nets.

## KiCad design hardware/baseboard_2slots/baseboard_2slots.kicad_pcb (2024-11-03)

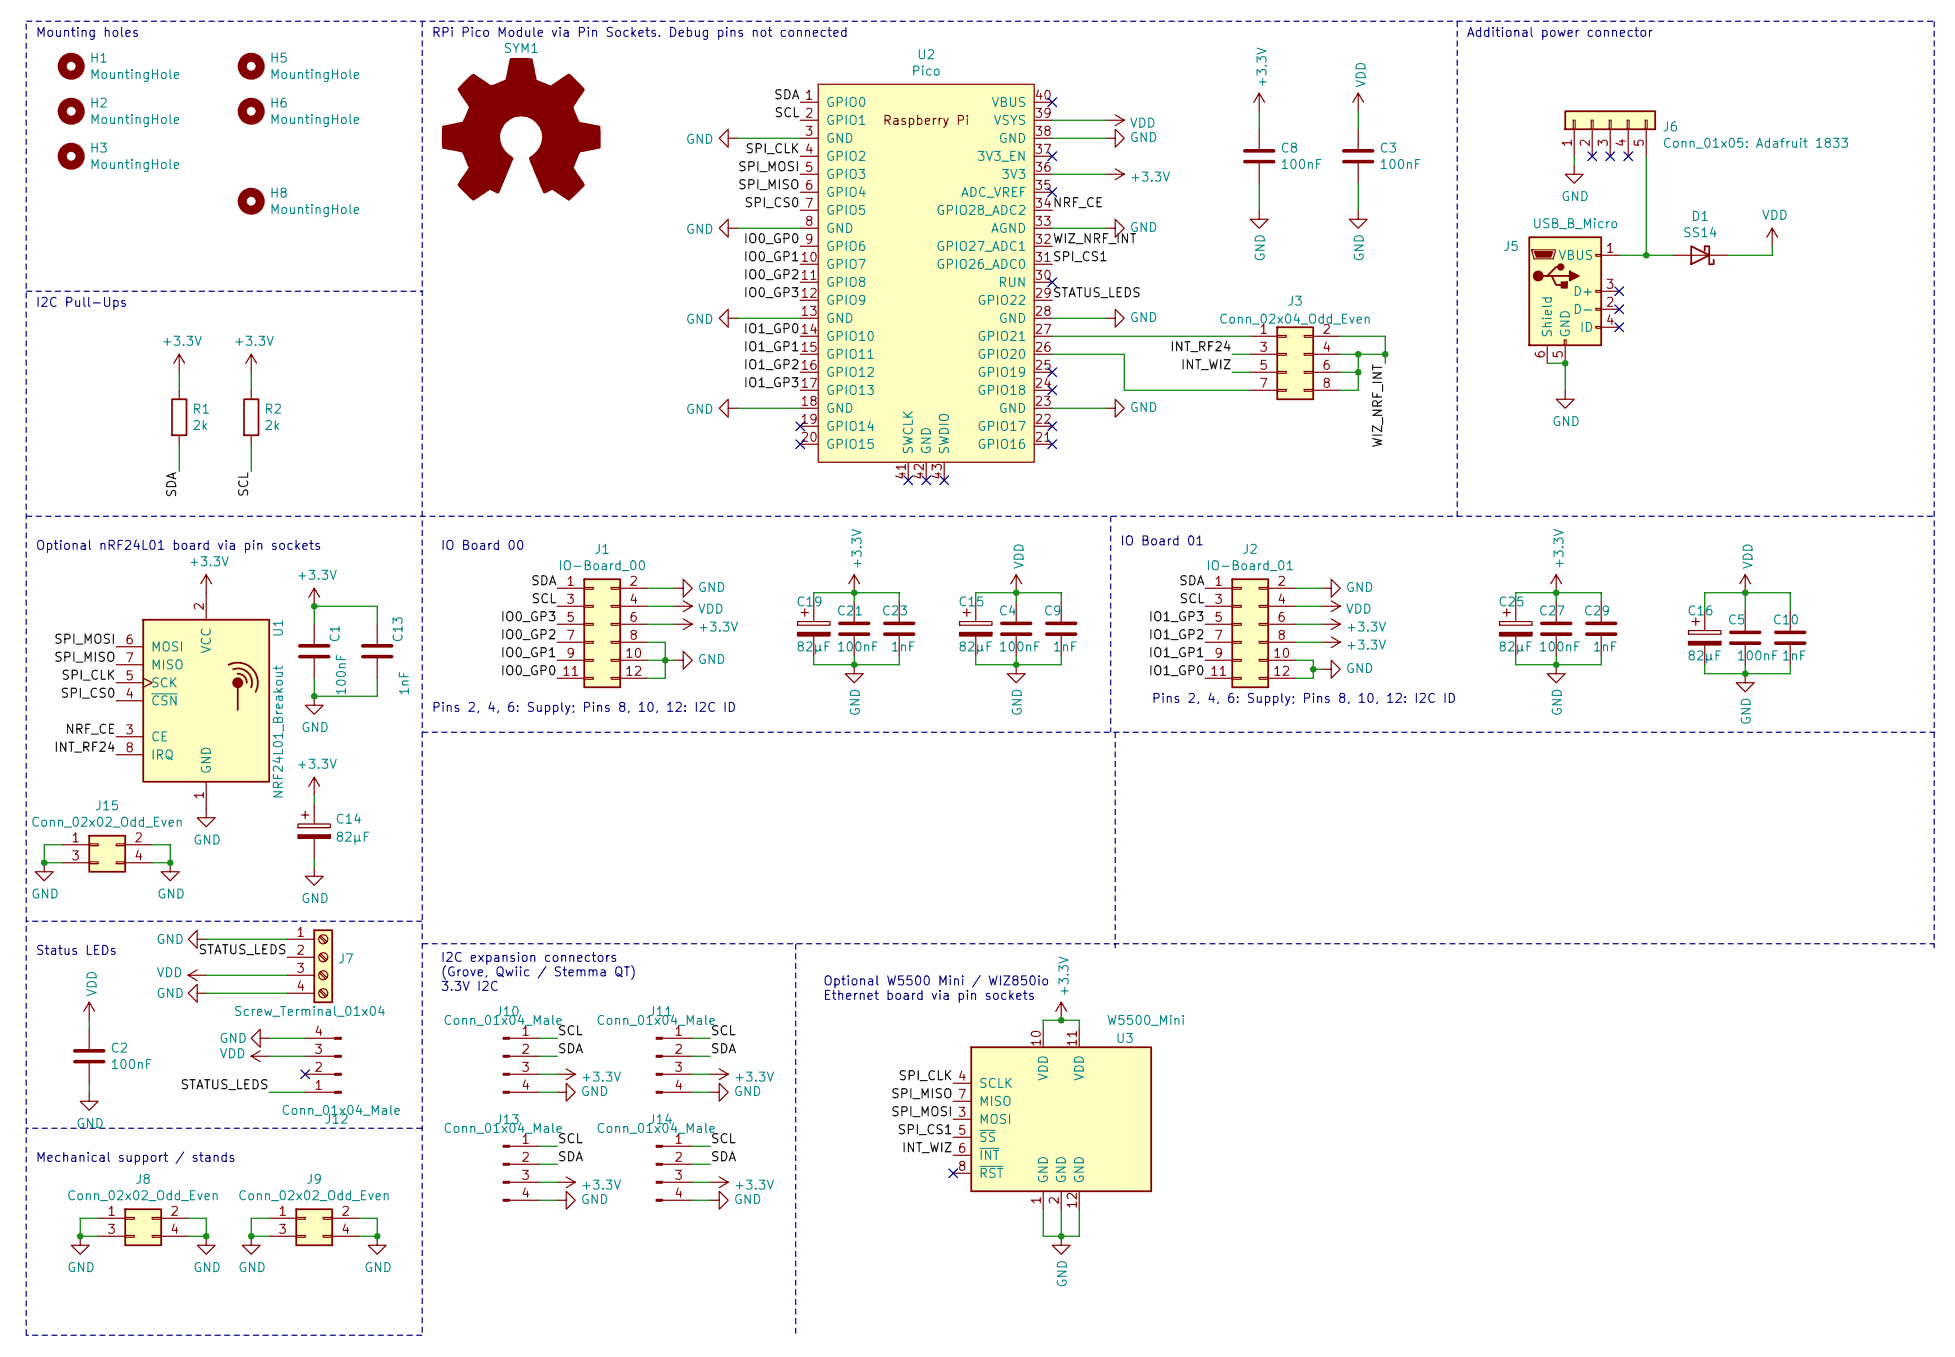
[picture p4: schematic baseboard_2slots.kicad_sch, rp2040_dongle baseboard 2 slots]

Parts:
C1, C2, C3, C4, C5, C8, C21, C27: 100nF; C_0603_1608Metric; LCSC C14663
C9, C10, C13, C23, C29: 1nF; C_0603_1608Metric; LCSC C1588
C14, C15, C16, C19, C25: 82µF; CP_Radial_D6.3mm_P2.50mm
D1: SS14; D_SMA; LCSC C2480
H1, H2, H3, H5, H6, H8: MountingHole; MountingHole_3.2mm_M3
J1: IO-Board_00; PinSocket_2x06_P2.54mm_Vertical
J2: IO-Board_01; PinSocket_2x06_P2.54mm_Vertical
J3: Conn_02x04_Odd_Even; PinHeader_2x04_P2.54mm_Vertical
J5: USB_B_Micro; USB_Micro-B_Wuerth_629105150521
J6: Conn_01x05: Adafruit 1833; PinHeader_1x05_P2.54mm_Vertical
J7: Screw_Terminal_01x04; TerminalBlock_Altech_AK300-4_P5.00mm
J8, J9: Conn_02x02_Odd_Even; PinHeader_2x02_P2.54mm_Vertical
J10, J11, J12: Conn_01x04_Male; NS-Tech_Grove_1x04_P2mm_Vertical
J13, J14: Conn_01x04_Male; JST_SH_BM04B-SRSS-TB_1x04-1MP_P1.00mm_Vertical
J15: Conn_02x02_Odd_Even; PinSocket_2x02_P2.54mm_Vertical
R1, R2: 2k; R_0805_2012Metric_Pad1.20x1.40mm_HandSolder; LCSC C17604
SYM1: Logo_Open_Hardware_Large; OSHW-Logo2_14.6x12mm_SilkScreen
U1: NRF24L01_Breakout; nRF24L01_Breakout
U2: Pico; RPi_Pico_SMD_TH
U3: W5500_Mini

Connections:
+3.3V: C1.1, C8.1, C13.1, C14.1, C19.1, C21.1, C23.1, C25.1, C27.1, C29.1, J1.6, J2.6, J2.8, J10.3, J11.3, J13.3, J14.3, R1.1, R2.1, U1.2 (VCC), U2.36 (3V3), U3.10 (VDD), U3.11 (VDD)
/INT_RF24: J3.3, U1.8 (IRQ)
/INT_WIZ: J3.5, U3.6 (~INT)
/IO0_GP0: J1.11, U2.9 (GPIO6)
/IO0_GP1: J1.9, U2.10 (GPIO7)
/IO0_GP2: J1.7, U2.11 (GPIO8)
/IO0_GP3: J1.5, U2.12 (GPIO9)
/IO1_GP0: J2.11, U2.14 (GPIO10)
/IO1_GP1: J2.9, U2.15 (GPIO11)
/IO1_GP2: J2.7, U2.16 (GPIO12)
/IO1_GP3: J2.5, U2.17 (GPIO13)
/NRF_CE: U1.3 (CE), U2.34 (GPIO28_ADC2)
/SCL: J1.3, J2.3, J10.1, J11.1, J13.1, J14.1, R2.2, U2.2 (GPIO1)
/SDA: J1.1, J2.1, J10.2, J11.2, J13.2, J14.2, R1.2, U2.1 (GPIO0)
/SPI_CLK: U1.5 (SCK), U2.4 (GPIO2), U3.4 (SCLK)
/SPI_CS0: U1.4 (~CSN), U2.7 (GPIO5)
/SPI_CS1: U2.31 (GPIO26_ADC0), U3.5 (~SS)
/SPI_MISO: U1.7 (MISO), U2.6 (GPIO4), U3.7 (MISO)
/SPI_MOSI: U1.6 (MOSI), U2.5 (GPIO3), U3.3 (MOSI)
/STATUS_LEDS: J7.2, J12.1, U2.29 (GPIO22)
/WIZ_NRF_INT: J3.2, J3.4, J3.6, J3.8, U2.32 (GPIO27_ADC1)
GND: C1.2, C2.2, C3.2, C4.2, C5.2, C8.2, C9.2, C10.2, C13.2, C14.2, C15.2, C16.2, C19.2, C21.2, C23.2, C25.2, C27.2, C29.2, J1.2, J1.8, J1.10, J1.12, J2.2, J2.10, J2.12, J5.5 (GND), J5.6 (Shield), J6.1, J7.1, J7.4, J8.1, J8.2, J8.3, J8.4, J9.1, J9.2, J9.3, J9.4, J10.4, J11.4, J12.4, J13.4, J14.4, J15.1, J15.2, J15.3, J15.4, U1.1 (GND), U2.3 (GND), U2.8 (GND), U2.13 (GND), U2.18 (GND), U2.23 (GND), U2.28 (GND), U2.33 (AGND), U2.38 (GND), U3.1 (GND), U3.2 (GND), U3.12 (GND)
unnamed: D1.2 (A), J5.1 (VBUS), J6.5
unnamed: J3.1, U2.27 (GPIO21)
unnamed: J3.7, U2.26 (GPIO20)
VDD: C2.1, C3.1, C4.1, C5.1, C9.1, C10.1, C15.1, C16.1, D1.1 (K), J1.4, J2.4, J7.3, J12.3, U2.39 (VSYS)

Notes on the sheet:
Pins 2, 4, 6: Supply; Pins 8, 10, 12: I2C ID
Additional power connector
Mounting holes
RPi Pico Module via Pin Sockets. Debug pins not connected
IO Board 00
I2C Pull-Ups
Status LEDs
Optional nRF24L01 board via pin sockets
IO Board 01
Mechanical support / stands
I2C expansion connectors (Grove, Qwiic / Stemma QT) 3.3V I2C
Optional W5500 Mini / WIZ850io Ethernet board via pin sockets

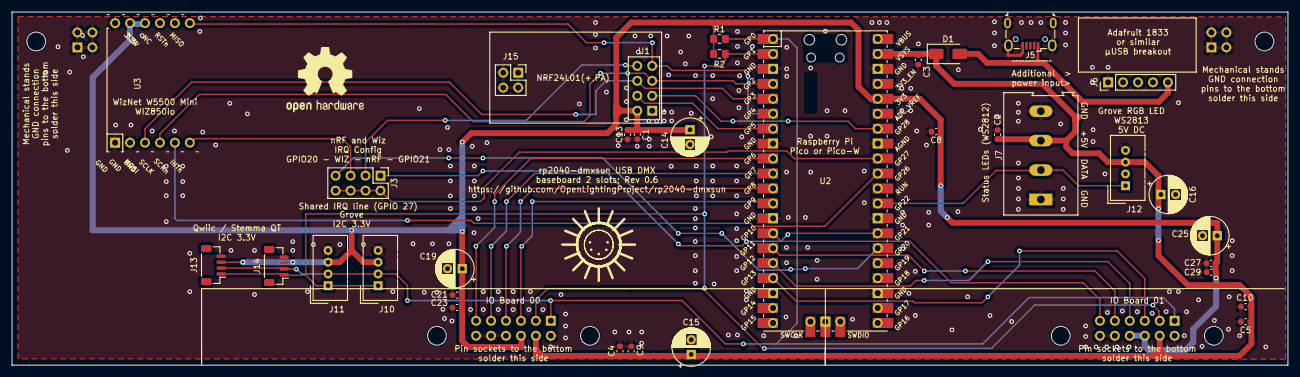
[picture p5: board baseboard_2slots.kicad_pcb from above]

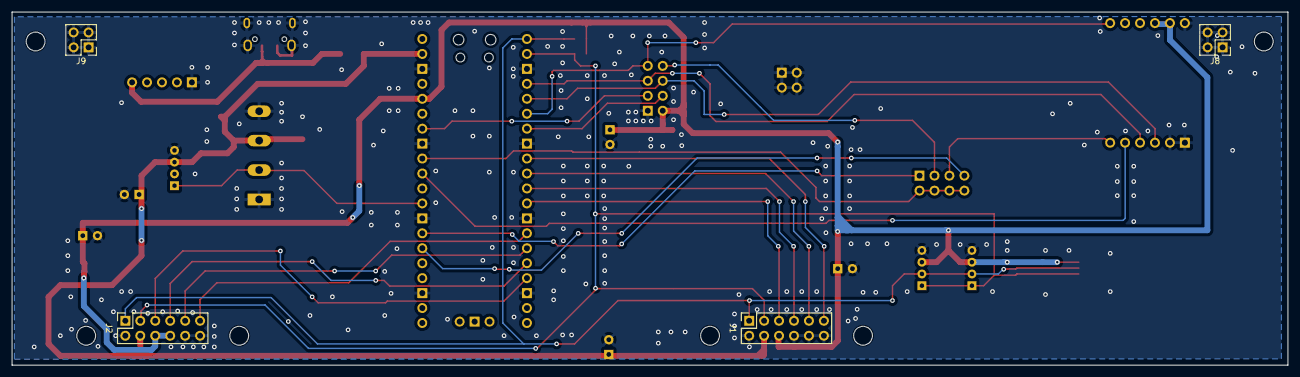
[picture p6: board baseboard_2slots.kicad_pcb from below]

Board: 2 copper layers, 216.8 x 60.0 mm, 45 parts (4 on the bottom side), 26 nets.

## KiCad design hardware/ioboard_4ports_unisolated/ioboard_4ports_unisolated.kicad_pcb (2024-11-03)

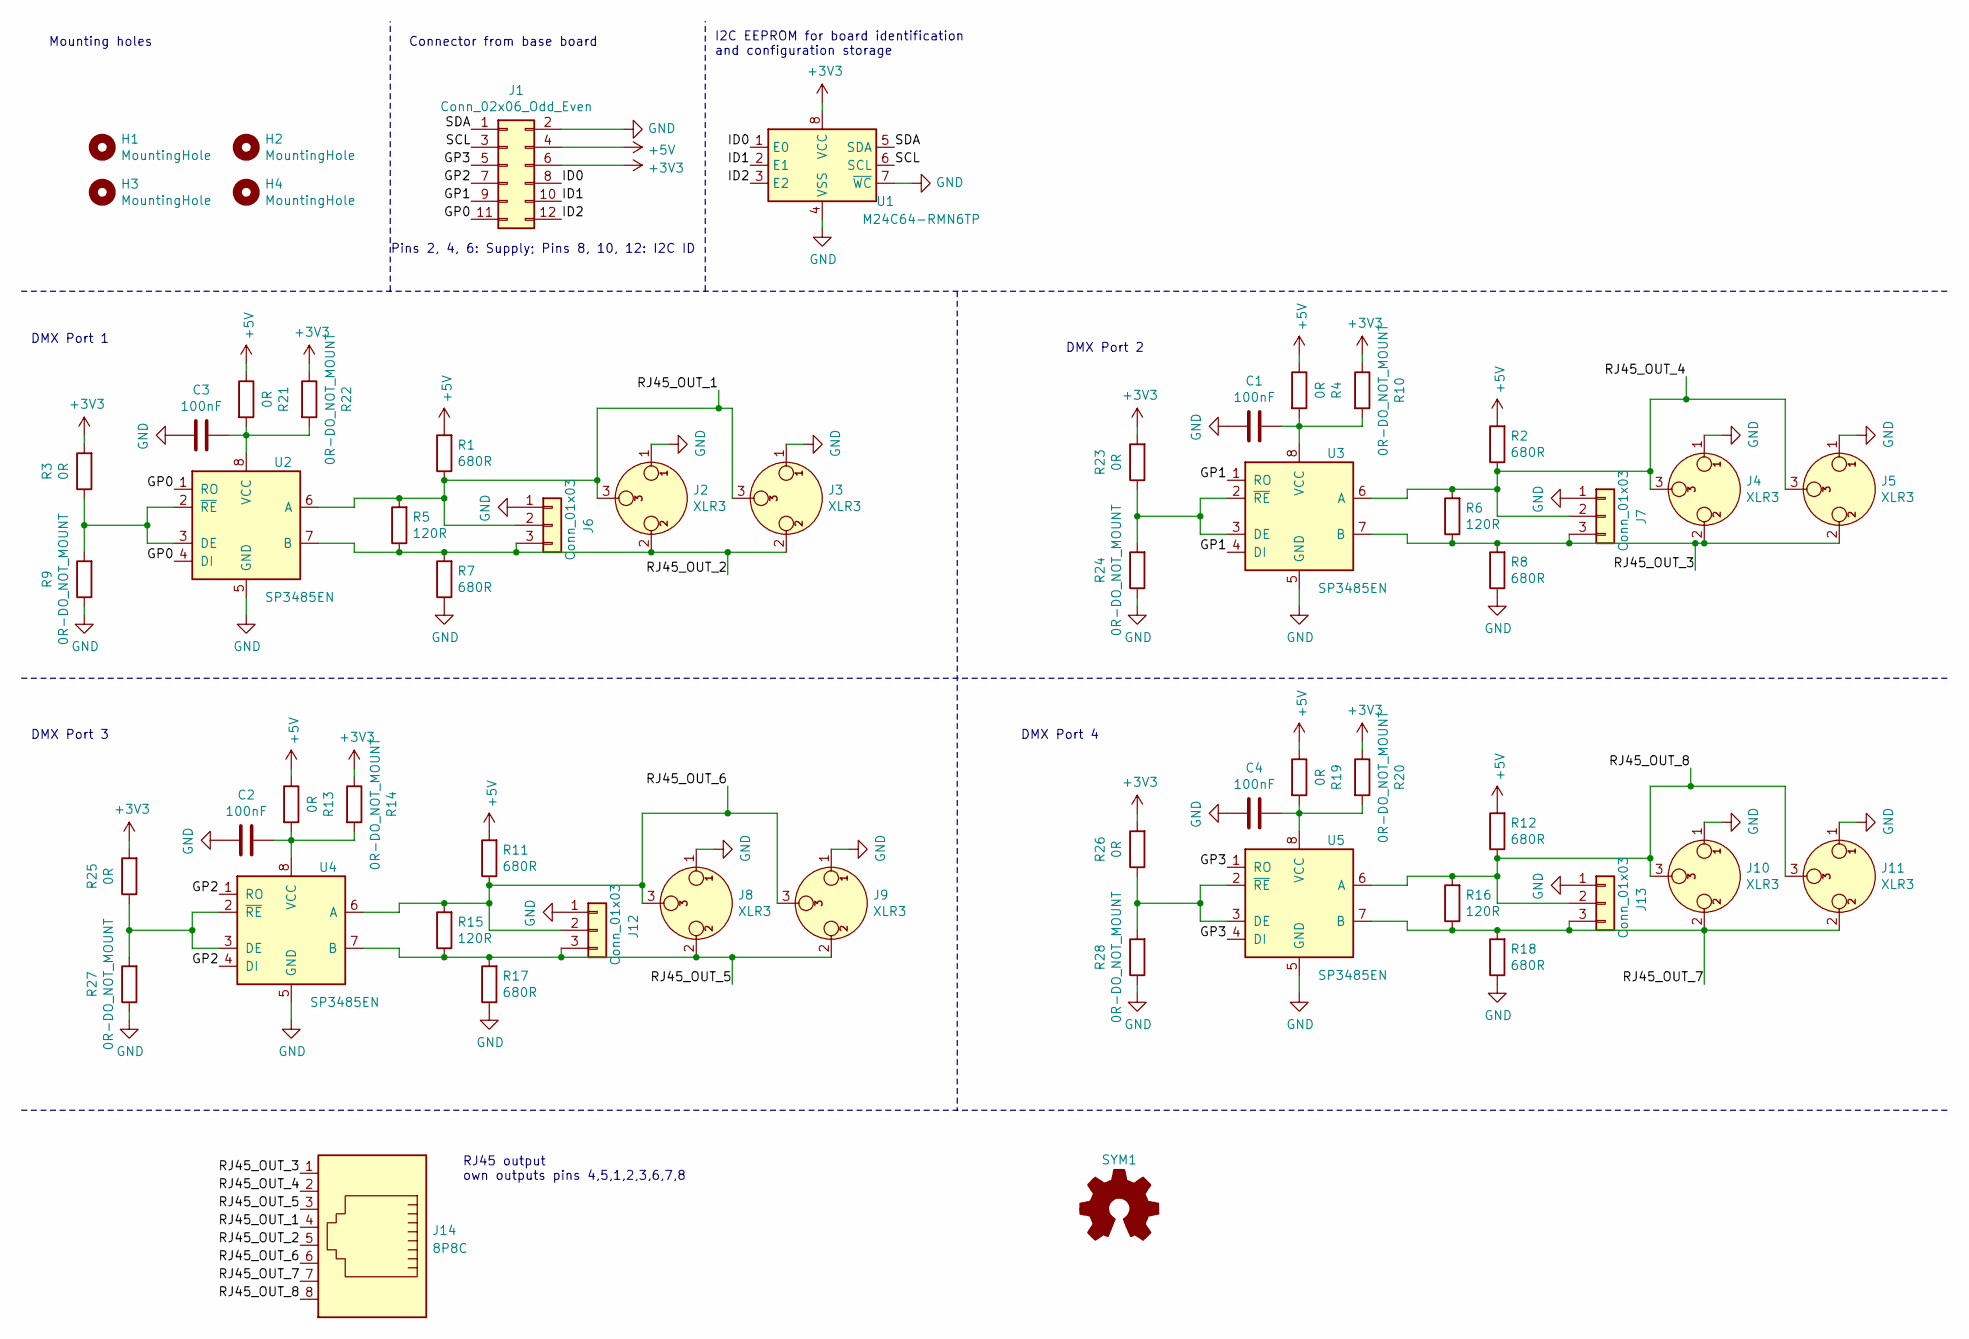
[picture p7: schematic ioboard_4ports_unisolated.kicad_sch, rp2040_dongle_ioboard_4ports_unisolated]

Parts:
C1, C2, C3, C4: 100nF; C_0603_1608Metric; LCSC C14663
H1, H2, H3, H4: MountingHole; MountingHole_3.2mm_M3
J1: Conn_02x06_Odd_Even; PinHeader_2x06_P2.54mm_Vertical
J2, J4, J8, J10: XLR3; Jack_XLR_Neutrik_NC3FAAH_Horizontal
J3, J5, J9, J11: XLR3; Jack_XLR_Neutrik_NC3FD-H_Horizontal
J6, J7, J12, J13: Conn_01x03; PinHeader_1x03_P2.54mm_Vertical
J14: 8P8C; RJ45_Sparkfun
R1, R2, R7, R8, R11, R12, R17, R18: 680R; R_0603_1608Metric_Pad0.98x0.95mm_HandSolder; LCSC C23228
R3, R4, R13, R19, R21, R23, R25, R26: 0R; R_0805_2012Metric_Pad1.20x1.40mm_HandSolder; LCSC C17477
R5, R6, R15, R16: 120R; R_0603_1608Metric_Pad0.98x0.95mm_HandSolder; LCSC C22787
R9, R10, R14, R20, R22, R24, R27, R28: 0R-DO_NOT_MOUNT; R_0805_2012Metric_Pad1.20x1.40mm_HandSolder; LCSC C17477
SYM1: Logo_Open_Hardware_Small; OSHW-Logo2_7.3x6mm_SilkScreen
U1: M24C64-RMN6TP; SOIC-8_3.9x4.9mm_P1.27mm; LCSC C79988
U2, U3, U4, U5: SP3485EN; SOIC-8_3.9x4.9mm_P1.27mm; LCSC C8963

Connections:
+3V3: J1.6, R3.2, R10.1, R14.1, R20.1, R22.1, R23.2, R25.2, R26.2, U1.8 (VCC)
+5V: J1.4, R1.2, R2.2, R4.1, R11.2, R12.2, R13.1, R19.1, R21.1
/GP0: J1.11, U2.1 (RO), U2.4 (DI)
/GP1: J1.9, U3.1 (RO), U3.4 (DI)
/GP2: J1.7, U4.1 (RO), U4.4 (DI)
/GP3: J1.5, U5.1 (RO), U5.4 (DI)
/ID0: J1.8, U1.1 (E0)
/ID1: J1.10, U1.2 (E1)
/ID2: J1.12, U1.3 (E2)
/RJ45_OUT_1: J2.3, J3.3, J6.2, J14.4, R1.1, R5.2, U2.6 (A)
/RJ45_OUT_2: J2.2, J3.2, J6.3, J14.5, R5.1, R7.2, U2.7 (B)
/RJ45_OUT_3: J4.2, J5.2, J7.3, J14.1, R6.1, R8.2, U3.7 (B)
/RJ45_OUT_4: J4.3, J5.3, J7.2, J14.2, R2.1, R6.2, U3.6 (A)
/RJ45_OUT_5: J8.2, J9.2, J12.3, J14.3, R15.1, R17.2, U4.7 (B)
/RJ45_OUT_6: J8.3, J9.3, J12.2, J14.6, R11.1, R15.2, U4.6 (A)
/RJ45_OUT_7: J10.2, J11.2, J13.3, J14.7, R16.1, R18.2, U5.7 (B)
/RJ45_OUT_8: J10.3, J11.3, J13.2, J14.8, R12.1, R16.2, U5.6 (A)
/SCL: J1.3, U1.6 (SCL)
/SDA: J1.1, U1.5 (SDA)
GND: C1.2, C2.2, C3.2, C4.2, J1.2, J2.1, J3.1, J4.1, J5.1, J6.1, J7.1, J8.1, J9.1, J10.1, J11.1, J12.1, J13.1, R7.1, R8.1, R9.1, R17.1, R18.1, R24.1, R27.1, R28.1, U1.4 (VSS), U1.7 (~WC), U2.5 (GND), U3.5 (GND), U4.5 (GND), U5.5 (GND)
unnamed: R3.1, R9.2, U2.2 (~RE), U2.3 (DE)
unnamed: C3.1, R21.2, R22.2, U2.8 (VCC)
unnamed: R23.1, R24.2, U3.2 (~RE), U3.3 (DE)
unnamed: C1.1, R4.2, R10.2, U3.8 (VCC)
unnamed: R25.1, R27.2, U4.2 (~RE), U4.3 (DE)
unnamed: C2.1, R13.2, R14.2, U4.8 (VCC)
unnamed: R26.1, R28.2, U5.2 (~RE), U5.3 (DE)
unnamed: C4.1, R19.2, R20.2, U5.8 (VCC)

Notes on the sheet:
DMX Port 1
RJ45 output own outputs pins 4,5,1,2,3,6,7,8
DMX Port 4
I2C EEPROM for board identification and configuration storage
DMX Port 2
Connector from base board
DMX Port 3
Pins 2, 4, 6: Supply; Pins 8, 10, 12: I2C ID
Mounting holes

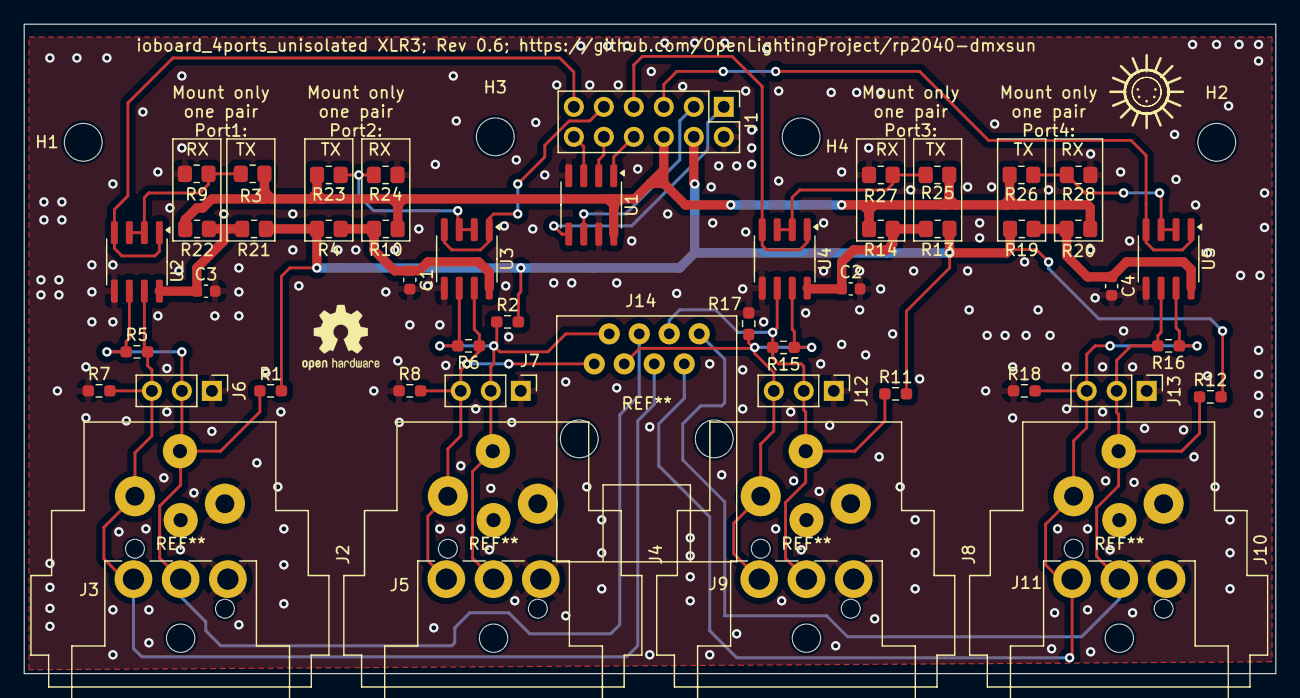
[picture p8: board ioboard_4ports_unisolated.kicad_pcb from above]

Board: 2 copper layers, 106.0 x 55.0 mm, 56 parts (0 on the bottom side), 28 nets.

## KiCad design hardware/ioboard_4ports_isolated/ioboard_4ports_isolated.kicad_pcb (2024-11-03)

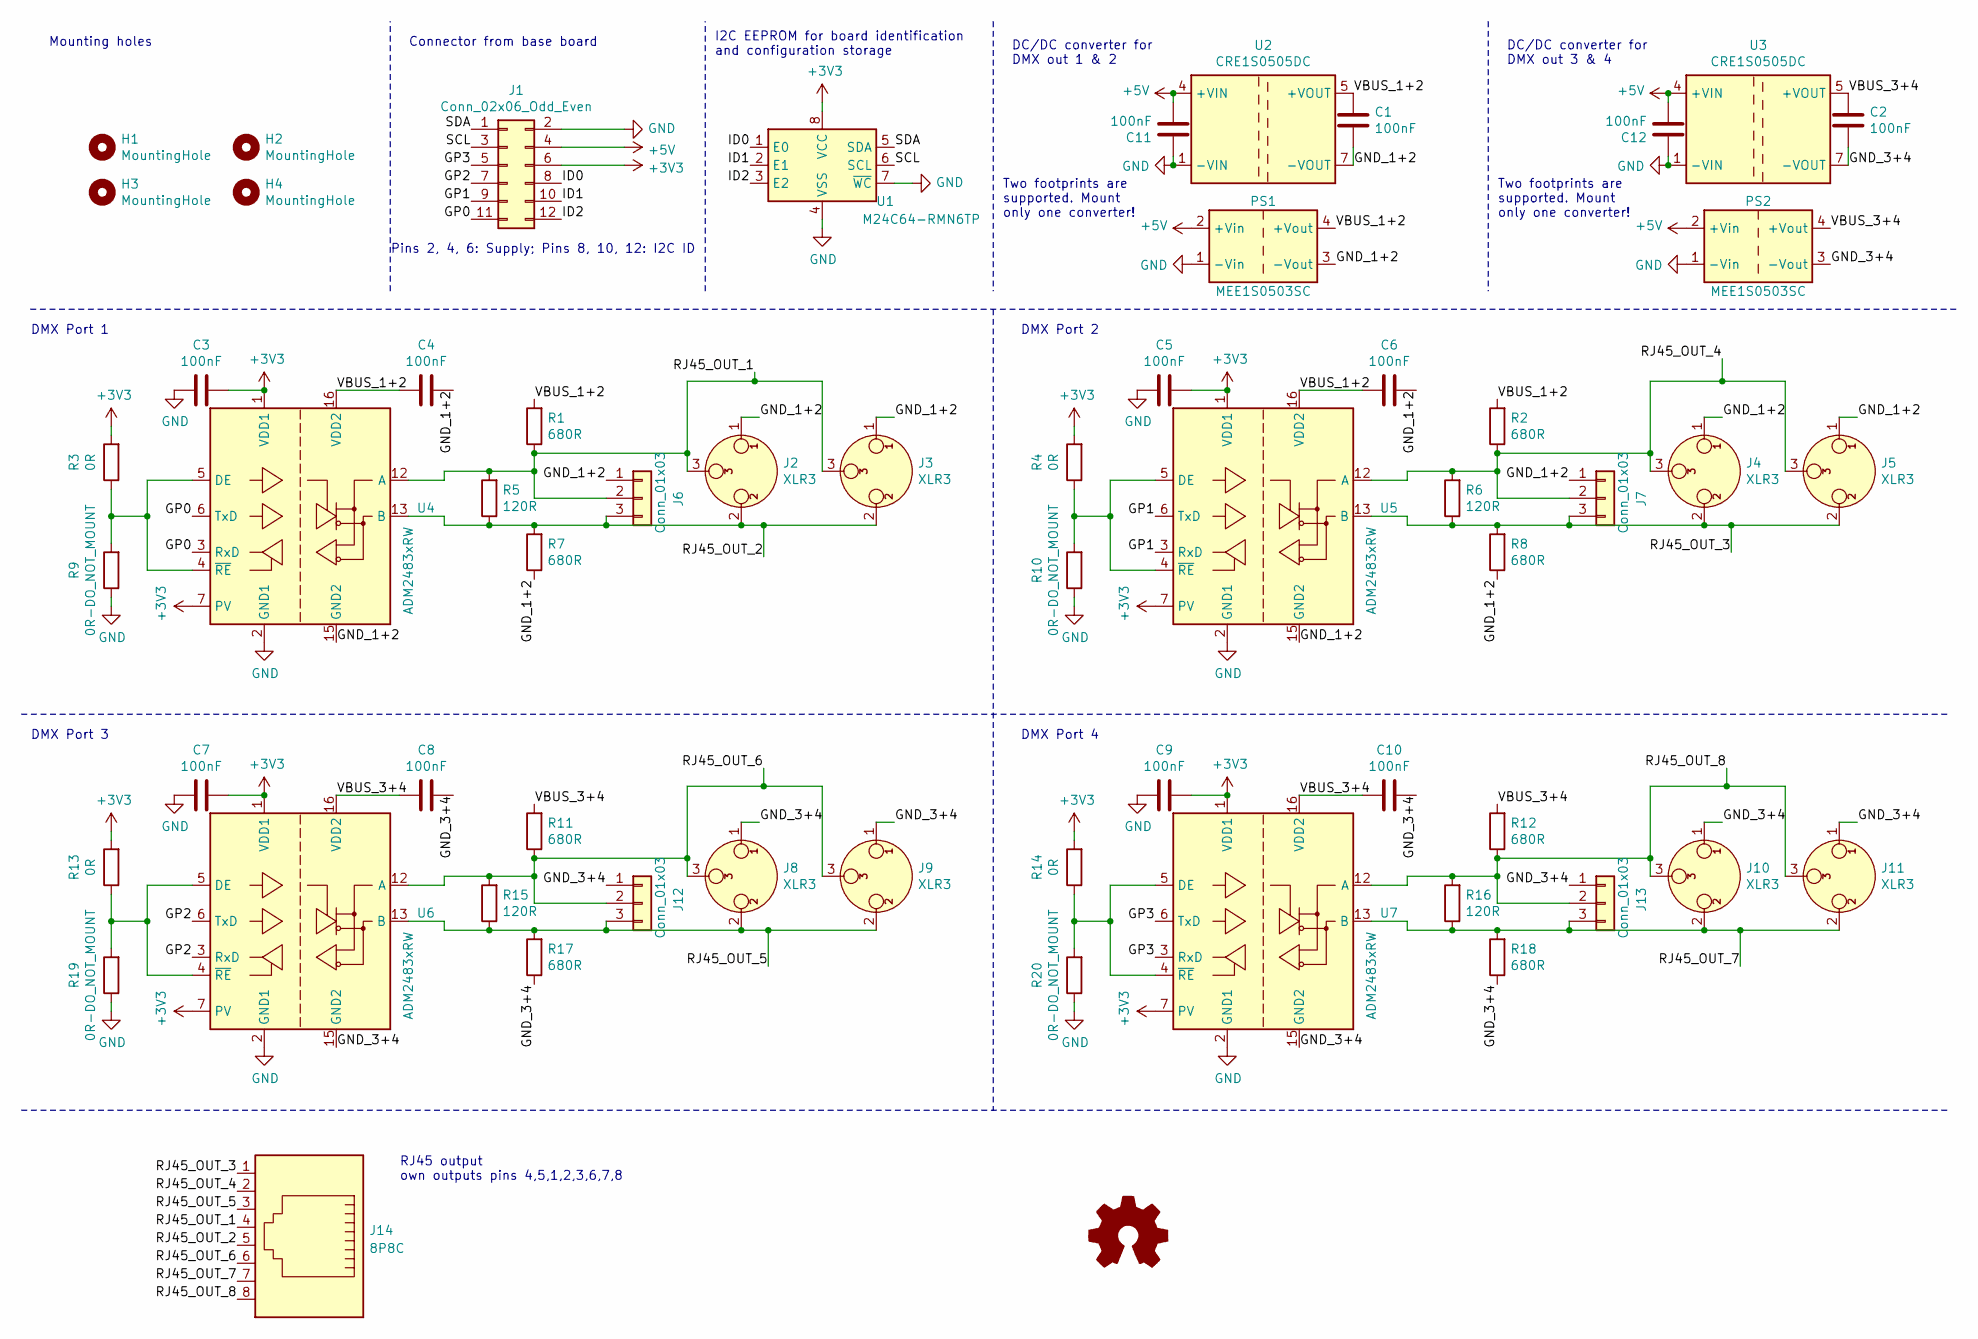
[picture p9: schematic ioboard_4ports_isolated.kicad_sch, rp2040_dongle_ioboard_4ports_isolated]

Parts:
C1, C2, C3, C4, C5, C6, C7, C8, C9, C10, C11, C12: 100nF; C_0603_1608Metric; LCSC C14663
H1, H2, H3, H4: MountingHole; MountingHole_3.2mm_M3
J1: Conn_02x06_Odd_Even; PinHeader_2x06_P2.54mm_Vertical
J2, J4, J8, J10: XLR3; Jack_XLR_Neutrik_NC3FAAH_Horizontal
J3, J5, J9, J11: XLR3; Jack_XLR_Neutrik_NC3FD-H_Horizontal
J6, J7, J12, J13: Conn_01x03; PinHeader_1x03_P2.54mm_Vertical
J14: 8P8C; RJ45_Sparkfun
PS1, PS2: MEE1S0503SC; Converter_DCDC_Murata_CRE1xxxxxx3C_THT
R1, R2, R7, R8, R11, R12, R17, R18: 680R; R_0603_1608Metric_Pad0.98x0.95mm_HandSolder; LCSC C23228
R3, R4, R13, R14: 0R; R_0805_2012Metric_Pad1.20x1.40mm_HandSolder; LCSC C17477
R5, R6, R15, R16: 120R; R_0603_1608Metric_Pad0.98x0.95mm_HandSolder; LCSC C22787
R9, R10, R19, R20: 0R-DO_NOT_MOUNT; R_0805_2012Metric_Pad1.20x1.40mm_HandSolder; LCSC C17477
SYM1: Logo_Open_Hardware_Small; OSHW-Logo2_7.3x6mm_SilkScreen
U1: M24C64-RMN6TP; SOIC-8_3.9x4.9mm_P1.27mm; LCSC C79988
U2, U3: CRE1S0505DC; Converter_DCDC_Murata_CRE1xxxxxxDC_THT
U4, U5, U6, U7: ADM2483xRW; SOIC-16W_7.5x10.3mm_P1.27mm; LCSC C9637

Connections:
+3V3: C3.1, C5.1, C7.1, C9.1, J1.6, R3.2, R4.2, R13.2, R14.2, U1.8 (VCC), U4.1 (VDD1), U4.7 (PV), U5.1 (VDD1), U5.7 (PV), U6.1 (VDD1), U6.7 (PV), U7.1 (VDD1), U7.7 (PV)
+5V: C11.1, C12.1, J1.4, PS1.2 (+Vin), PS2.2 (+Vin), U2.4 (+VIN), U3.4 (+VIN)
/GND_1+2: C1.1, C4.1, C6.1, J2.1, J3.1, J4.1, J5.1, J6.1, J7.1, PS1.3 (-Vout), R7.1, R8.1, U2.7 (-VOUT), U4.9 (GND2), U4.15 (GND2), U5.9 (GND2), U5.15 (GND2)
/GND_3+4: C2.1, C8.1, C10.1, J8.1, J9.1, J10.1, J11.1, J12.1, J13.1, PS2.3 (-Vout), R17.1, R18.1, U3.7 (-VOUT), U6.9 (GND2), U6.15 (GND2), U7.9 (GND2), U7.15 (GND2)
/GP0: J1.11, U4.3 (RxD), U4.6 (TxD)
/GP1: J1.9, U5.3 (RxD), U5.6 (TxD)
/GP2: J1.7, U6.3 (RxD), U6.6 (TxD)
/GP3: J1.5, U7.3 (RxD), U7.6 (TxD)
/ID0: J1.8, U1.1 (E0)
/ID1: J1.10, U1.2 (E1)
/ID2: J1.12, U1.3 (E2)
/RJ45_OUT_1: J2.3, J3.3, J6.2, J14.4, R1.1, R5.2, U4.12 (A)
/RJ45_OUT_2: J2.2, J3.2, J6.3, J14.5, R5.1, R7.2, U4.13 (B)
/RJ45_OUT_3: J4.2, J5.2, J7.3, J14.1, R6.1, R8.2, U5.13 (B)
/RJ45_OUT_4: J4.3, J5.3, J7.2, J14.2, R2.1, R6.2, U5.12 (A)
/RJ45_OUT_5: J8.2, J9.2, J12.3, J14.3, R15.1, R17.2, U6.13 (B)
/RJ45_OUT_6: J8.3, J9.3, J12.2, J14.6, R11.1, R15.2, U6.12 (A)
/RJ45_OUT_7: J10.2, J11.2, J13.3, J14.7, R16.1, R18.2, U7.13 (B)
/RJ45_OUT_8: J10.3, J11.3, J13.2, J14.8, R12.1, R16.2, U7.12 (A)
/SCL: J1.3, U1.6 (SCL)
/SDA: J1.1, U1.5 (SDA)
/VBUS_1+2: C1.2, C4.2, C6.2, PS1.4 (+Vout), R1.2, R2.2, U2.5 (+VOUT), U4.16 (VDD2), U5.16 (VDD2)
/VBUS_3+4: C2.2, C8.2, C10.2, PS2.4 (+Vout), R11.2, R12.2, U3.5 (+VOUT), U6.16 (VDD2), U7.16 (VDD2)
GND: C3.2, C5.2, C7.2, C9.2, C11.2, C12.2, J1.2, PS1.1 (-Vin), PS2.1 (-Vin), R9.1, R10.1, R19.1, R20.1, U1.4 (VSS), U1.7 (~WC), U2.1 (-VIN), U3.1 (-VIN), U4.2 (GND1), U4.8 (GND1), U5.2 (GND1), U5.8 (GND1), U6.2 (GND1), U6.8 (GND1), U7.2 (GND1), U7.8 (GND1)
unnamed: R3.1, R9.2, U4.4 (~RE), U4.5 (DE)
unnamed: R4.1, R10.2, U5.4 (~RE), U5.5 (DE)
unnamed: R13.1, R19.2, U6.4 (~RE), U6.5 (DE)
unnamed: R14.1, R20.2, U7.4 (~RE), U7.5 (DE)

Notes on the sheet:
DMX Port 1
DMX Port 2
DC/DC converter for DMX out 1 & 2
Mounting holes
DMX Port 3
DC/DC converter for DMX out 3 & 4
Pins 2, 4, 6: Supply; Pins 8, 10, 12: I2C ID
Two footprints are supported. Mount only one converter!
RJ45 output own outputs pins 4,5,1,2,3,6,7,8
Connector from base board
DMX Port 4
I2C EEPROM for board identification and configuration storage

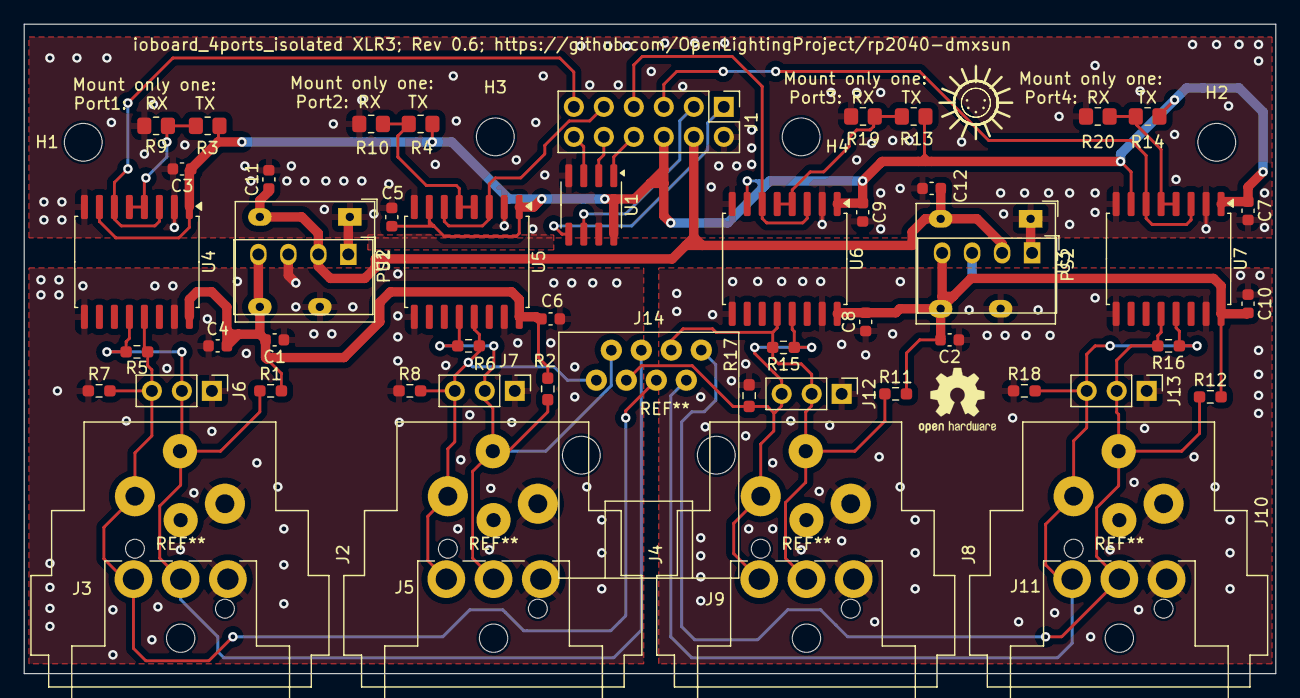
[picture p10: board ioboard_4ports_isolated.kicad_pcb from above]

Board: 2 copper layers, 106.0 x 55.0 mm, 60 parts (0 on the bottom side), 28 nets.

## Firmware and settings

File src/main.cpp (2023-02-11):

/**
 * Copyright (c) 2021 Open Lighting Project
 *
 * SPDX-License-Identifier: GPL-3.0
 */

extern "C" {
#include <stdio.h>
#include <hardware/clocks.h>    // Needed for the onboard LED blinking patterns
#include <hardware/dma.h>       // To control the data transfer from mem to pio
#include <hardware/gpio.h>      // To "manually" control the trigger pin
#include <hardware/adc.h>       // Pico-W runtime detection

#include <pico/stdlib.h>
#include "pico/multicore.h"

#include <pico/cyw43_arch.h>    // Toggle the LED on the Pico-W

#include "pins.h"
#include "picotool_binary_information.h"

#include "stdio_usb.h"
}

#include "log.h"
#include "dmxbuffer.h"
#include "statusleds.h"
#include "boardconfig.h"
#include "webserver.h"
#include "wireless.h"
#include "localdmx.h"
#include "eth_cyw43.h"
#include "oled_u8g2.h"

#include "dhcpdata.h"

#include "usb_EDP.h"
#include "usb_NodleU1.h"

#include "udp_artnet.h"
#include "udp_e1_31.h"
#include "udp_edp.h"

extern "C" {
#include <bsp/board.h>          // On-board-LED
#include <tusb.h>
}

/* On-board LED blinking patterns
 * The values here are clock dividers for the on-chip RTC-clock running at
 * 46875Hz. Using that value gives a "PWM" with 1s cycle time and 50% duty cycle
 *
 * DIVIDER | Cycle time | Description
 * 2000    |   ~43ms    | Init phase, board not ready
 * 65535   | ~1.4s      | Board ready, all chans in all universes are 0
 * 42188   | ~0.9s      | Board ready, one universe with at least one channel != 0
 * 21094   | ~0.45s     | Board ready, multiple universes with at least one channel != 0
 */
// TODO: Replace the clock-derived LED-blinking with a software-controlled one
//       Reason: If the board crashed, the LED currently blinks on. It should stop doing so
enum {
    BLINK_INIT                 =  2000,
    BLINK_READY_NO_DATA        = 65535,
    BLINK_READY_SINGLE_UNI     = 42188,
    BLINK_READY_MULTI_UNI      = 21094,

};
#define BLINK_LED(div) clock_gpio_init(PIN_LED_PICO, CLOCKS_CLK_GPOUT0_CTRL_AUXSRC_VALUE_CLK_RTC, div);

// Super-globals (for all modules)
Log logger;
DmxBuffer dmxBuffer;
LocalDmx localDmx;
StatusLeds statusLeds;
Oled_u8g2 oled_u8g2;
BoardConfig boardConfig;
WebServer webServer;
Wireless wireless;
Eth_cyw43 eth_cyw43;
DhcpData dhcpdata;

critical_section_t bufferLock;

uint8_t usbTraffic = 0;

struct repeating_timer led_toggle_timer;

bool led_toggle_timer_callback(repeating_timer_t *rt);
void led_blinking_task(void);

void core1_tasks(void);

// Board init sequence:
// 1. Status LEDs
// 2. Detect IO boards
// 3. Read board configuration from "first" IO board
// 3b. If no IO board was detected: Read board config from last sector of on-board flash
//     (This could be the case for nRF24 mesh masters with attached PC and no local IO
//      or nRF24 mesh repeaters with no local IO)
// 4. Depending on config: USB host-interface (style of emulation)
// 5. tusb_init(), stdio_usb_init() and configure magic-baudrate-reboot
// 6. Depending on config (IP addresses): USB-Network-Web-Server
// 7. nRF24 detection and init
// 8. Depending on base boards and config: DMX PIOs and GPIO config

int main() {
    // Runtime-detect which board we are running on
    adc_init();
    // Make sure GPIO is high-impedance, no pullups etc
    adc_gpio_init(29);
    // Select ADC input 3 (GPIO29)
    adc_select_input(3);
    // Give some time for the voltage to stabilize and the ADC to sample
    sleep_ms(5);
    uint16_t firstRead = adc_read();
    BoardConfig::boardIsPicoW = (firstRead < 1000);

    // Make the onboard-led blink like crazy during the INIT phase
    // without having to do this in software because we're busy with other stuff
    if (!BoardConfig::boardIsPicoW) {
        BLINK_LED(BLINK_INIT);
    }

    // /!\ Do NOT use LOG() until TinyUSB-stack has been initialized /!\

    // Phase 0: Overclock the board to 250MHz. According to
    //          https://www.youtube.com/watch?v=G2BuoFNLo this should be
    //          totally safe with the default 1.10V Vcore
    set_sys_clock_khz(250000, true);

    // Phase 1: Init the status LEDs
    statusLeds.init();
    statusLeds.setBrightness(20);
    statusLeds.writeLeds();

    // Phase 2: Detect and read IO boards
    boardConfig.init();
    boardConfig.readIOBoards();

    oled_u8g2.scanBusForOLED();
    if (oled_u8g2.oledAvailable) {
        oled_u8g2.init();
    }

    // Phase 2b: Init our DMX buffers
    critical_section_init(&bufferLock);
    dmxBuffer.init();

    // Phase 3: Make sure we have some configuration ready (includes Phase 3b)
    boardConfig.prepareConfig();

    // Phase 4, USB configuration happens in usb_descriptors (boardConfig is queried)
    //          However, we would need to instantiate the relevant class here
    Usb_EDP::init();
    Usb_NodleU1::init();

    // Phase 5: Enable the USB interface, the debugging console, ...
    tusb_init();
    stdio_usb_init();
    logger.init();

    // Phase 6: Fire up the integrated web server
    // This also initialises the TinyUSB<->lwIP glue. lwIP and the DHCP server
    dhcpdata.init();

    if (BoardConfig::boardIsPicoW) {
        // pico_cyw43_arch automatically and unconditionally calls lwip_init ...
        eth_cyw43.init();
    } else {
        // Since we didn't init pico_cyw43_arch, we call lwip_init now
        // TODO?: Not using an async_context as of now
        lwip_init();
    }

    init_tinyusb_netif();   // Init TinyUSB's lwip integration and the netif
    wait_for_netif_is_up(); // TinyUSB network interface
    dhcpd_init();

    webServer.init();

    // Phase 7: Detect if there is a radio module and init it if so
    wireless.init();

    // Phase 8: Set up PIOs and GPIOs according to the IO boards
    localDmx.init();

    // Re-init the PICO-LED to a normal LED
    gpio_init(PIN_LED_PICO);
    gpio_set_dir(PIN_LED_PICO, GPIO_OUT);
    // Set up a timer to make status LED blink
    add_repeating_timer_ms(25, led_toggle_timer_callback, NULL, &led_toggle_timer);

    // Phase 9: Do all the patching between the internal DMX buffers and ports
    // Patching is read from BoardConfig and actually nothing needs to be done here

    // Phase 10: Start our ArtNet- and E1.31 receiver
    Udp_ArtNet::init();
    Udp_E1_31::init();
    Udp_EDP::init();

    // Finally, turn on the green component of the SYSTEM status LED
    statusLeds.setStaticOn(4, 0, 1, 0);
    sleep_ms(10);
    statusLeds.writeLeds();

    // SETUP COMPLETE
    LOG("SYSTEM: SETUP COMPLETE :D ADC read: %d", firstRead);

    // Run all important tasks at least once before we start AUX tasks on core1
    // so the USB device enumeration doesn't time-out
    tud_task();
    tud_task();
    tud_task();
    webServer.cyclicTask();

    // Now get core1 running ...
    LOG("SYSTEM: Starting core 1 ...");
    multicore_launch_core1(core1_tasks);

    LOG("SYSTEM: Time to party, entering main loop");

    // Enter the main loop on core0. localDmx (PIO) is interrupt driven.
    // Everything else (I assume) is polled and handled here.
    // Wireless is on core1 so waiting for ACKs won't slow down everything else
    while (true) {
        tud_task();

        if (tud_mounted()) {
            statusLeds.setStaticOn(5, 0, 1, 0);
        } else {
            statusLeds.setStaticOff(5, 0, 1, 0);
        }

        webServer.cyclicTask(); // Make sure this is on core0 since it
                                // WILL halt core1 when writing to the flash!

        if (BoardConfig::boardIsPicoW) {
            eth_cyw43.cyclicTask();
        }
//        wireless.cyclicTask();
//        statusLeds.cyclicTask();
//        led_blinking_task();
//        sleep_us(10);
    }
};

// Core1 handles wireless (which can delay quite a bit) + status LEDs
void core1_tasks() {
    while (true) {
//        tud_task();
//        webServer.cyclicTask();
        wireless.cyclicTask();
        statusLeds.cyclicTask();
        led_blinking_task();
//        sleep_us(10);
    }
};

// LED toggle task
bool led_toggle_timer_callback(repeating_timer_t *rt) {
    if (BoardConfig::boardIsPicoW) {
        cyw43_arch_gpio_put(PIN_LED_PICOW, !cyw43_arch_gpio_get(PIN_LED_PICOW));
    } else {
        gpio_put(PIN_LED_PICO, !gpio_get(PIN_LED_PICO));
    }
    return true;
}

//--------------------------------------------------------------------+
// BLINKING TASK
//--------------------------------------------------------------------+
void led_blinking_task(void) {
    // The following calculations take lots of time. However, this doesn't
    // matter since the DMX updating is done via IRQ handler

    // TODO: This iteration through all universes takes quite much time.
    //       Make the DmxBuffer remember for each universe if it's all 0s
    //       and read that property here

    uint universes_none_zero = 0;
    // Check the universes for non-zero channels
    for (uint16_t j = 0; j < 16; j++) {
        for (uint16_t i = 0; i < 512; i++) {
            if (dmxBuffer.buffer[j][i]) {
                universes_none_zero++;
                break;
            }
        }
        if (universes_none_zero > 4) {
            break;
        }
    }

    if (universes_none_zero == 0) {
        led_toggle_timer.delay_us = 1200 * 1000;
        statusLeds.setStatic(7, 0, 0, 0);
    } else if (universes_none_zero == 1) {
        led_toggle_timer.delay_us = 800 * 1000;
        statusLeds.setStatic(7, 0, 1, 0);
    } else if (universes_none_zero > 4) {
        led_toggle_timer.delay_us = 300 * 1000;
        statusLeds.setStatic(7, 1, 1, 1);
    } else if (universes_none_zero > 1) {
        statusLeds.setStatic(7, 0, 0, 1);
    }
}

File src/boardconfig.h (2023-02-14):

#ifndef BOARDCONFIG_H
#define BOARDCONFIG_H

#include "pins.h"

#ifdef __cplusplus
#include <RF24.h>
#endif

// The config area in the flash is the last sector since the smallest
// area we can erase is one sector. One sector is usually 4kByte large and
// the Pico's flash is 2048kByte large. Thus, the config area starts
// at offset 2044k.
// However, we are only using the first 2048 byte of that sector since
// that is how large the I2C EEPROMs on the IO boards are (since rev 0.7)
#define CONFIG_FLASH_OFFSET (PICO_FLASH_SIZE_BYTES - FLASH_SECTOR_SIZE)
// Remaining flash size for the "program" (including WebUI) is:
//   2093056 byte = 2044 kByte = 1,99609375 MByte ;)
// However, according to https://forums.raspberrypi.com/viewtopic.php?p=1867632&sid=b5fc2e594d2cd34b269be5600eef6ea8#p1867632
// the UF2-file contains so much padding that it can grow to 4 MByte before
// we completely fill the flash :D

#define MAX_PATCHINGS 32

// Config data types and layout
#define CONFIG_VERSION 7

#ifdef __cplusplus

enum BoardType : uint8_t {
    invalid_00                = 0x00,
    dmx_4ports_unisolated     = 0x01,
    dmx_4ports_isolated       = 0x02,
    dmx_2ports_rdm_unisolated = 0x03,
    dmx_2ports_rdm_isolated   = 0x04,

    led_4ports                = 0x20,

    config_only_dongle        = 0xfd,
    baseboard_fallback        = 0xfe,
    invalid_ff                = 0xff
};

enum PortParamsDirection : uint8_t {
    unknown                   = 0, // OR: Port doesn't exist on board
    out                       = 1, // DMX fixed sending port
    in                        = 2, // DMX fixed input port
    switchable                = 3, // Software-swichtable, RDM capable
};

enum PortParamsConnector : uint8_t {
    xlr_5_female              = 0,
    xlr_5_male                = 1,
    xlr_3_female              = 2,
    xlr_3_male                = 3,
    rj45                      = 4,
    screws                    = 5,
};

// Bits 0-1: Data direction
// Bits 2-4: Connector type
struct __attribute__((__packed__)) PortParams {
    PortParamsDirection direction : 2;
    PortParamsConnector connector : 4;
    uint8_t UNUSED                : 2;
};

enum UsbProtocol : uint8_t {
    EDP                       = 0, // Our "native" protocol only
    JaRule                    = 1, // Max 8 ports, each IN or OUT
    uDMX                      = 2, // One TX only, data comes in via CONTROL endpoint
    OpenDMX                   = 3, // Multiple (8?) serial endpoints
    NodleU1                   = 4, // Digital Enlightenment / DMXControl Projects e.V.
                                   // 1 universe standard, 16 with protocol modifications
    UsbPro                    = 5, // ENTTEC USB Pro. One IN or OUT
                                   // Not sure if we can/should actually do this since we
                                   // would need to properly emulate an FT*I chip for that
};

// Size: 2 byte
struct __attribute__((__packed__)) RadioParams {
    uint8_t compression           : 1;
    uint8_t allowSparse           : 1;
    rf24_datarate_e dataRate      : 3;
    rf24_pa_dbm_e txPower         : 3;
    uint8_t padding               : 8;
};

enum RadioRole : uint8_t {
    sniffer                   = 0, // RX only for spectrum scanning
    broadcast                 = 1, // Simple broadcast TX and RX
    mesh                      = 2, // RF24Mesh, can RX and TX universes
                                   // Role in mesh (master/node) is set by radioAddress
    QuickDMX_TX               = 3, // TODO: NOT IMPLEMENTED
    QuickDMX_RX               = 4, // TODO: NOT IMPLEMENTED
    APE_TX                    = 5, // TODO: NOT IMPLEMENTED
    APE_RX                    = 6, // TODO: NOT IMPLEMENTED
    D_Fi_TX                   = 7, // TODO: NOT IMPLEMENTED
    D_Fi_RX                   = 8, // TODO: NOT IMPLEMENTED
    Cameo_WDMX_TX             = 9, // TODO: NOT IMPLEMENTED
    Cameo_WDMX_RX            = 10, // TODO: NOT IMPLEMENTED
};

enum EthDhcpMode : uint8_t {
    staticIp                  = 0, // Static IP, no DHCP is tried
    dhcpWithFallback          = 1, // DHCP is tried, fallback to static IP
    dhcpOrFail                = 2, // DHCP is tried, module is disabled on failure
};

enum PatchType : uint8_t {
    buffer                    = 0, // Our internal DMX buffers
    local                     = 1, // Local DMX generation (GPIO via PIO)
    usbProto                  = 2, // From/to host via Serial or emulated protocol
    ip                        = 3, // From/to "host via UsbEth", Ethernet or WiFi

    nrf24                     = 5, // nRF24 wireless module connected via SPI
};
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

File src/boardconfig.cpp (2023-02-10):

#include "boardconfig.h"

#include "statusleds.h"
#include "log.h"

#include <hardware/gpio.h>
#include <hardware/i2c.h>
#include <hardware/flash.h>
#include <pico/unique_id.h>
#include "pico/multicore.h"

extern StatusLeds statusLeds;

extern void core1_tasks();

const uint8_t *config_flash_contents = (const uint8_t *) (XIP_BASE + CONFIG_FLASH_OFFSET);

ConfigData* BoardConfig::activeConfig;
ConfigSource BoardConfig::configSource = ConfigSource::Fallback;
uint8_t BoardConfig::shortId;
char BoardConfig::boardSerialString[25];
char BoardConfig::boardHostnameString[12];
bool BoardConfig::boardIsPicoW;


void BoardConfig::init() {
    i2c_init(i2c0, 100 * 1000);
    gpio_set_function(PIN_I2C_SCL, GPIO_FUNC_I2C);
    gpio_set_function(PIN_I2C_SDA, GPIO_FUNC_I2C);
    // Pull-ups are populated on the base board
    // However, we enable the internal ones as well, doesn't hurt
    // Please note that the external ones are required according to the
    // RP2040 datasheet and my measurements confirm that
    gpio_pull_up(PIN_I2C_SCL);
    gpio_pull_up(PIN_I2C_SDA);

    // Compute the third byte of the IP with a value from
    // the unique board id: 169.254.X.1 (board), 169.254.X.2 (host)
    pico_unique_board_id_t id;
    pico_get_unique_board_id(&id);
    shortId = id.id[6];
    snprintf(boardSerialString, 24, "dmxsun_%02x%02x%02x%02x%02x%02x%02x%02x",
        id.id[0],
        id.id[1],
        id.id[2],
        id.id[3],
        id.id[4],
        id.id[5],
        id.id[6],
        id.id[7]
    );

    snprintf(boardHostnameString, 11, "dmxsun_%d",
        shortId
    );

    memset(this->rawData, 0xff, 5*2048);
}

void BoardConfig::readIOBoards() {
    this->responding[0] = false;
    this->responding[1] = false;
    this->responding[2] = false;
    this->responding[3] = false;

    for (int addr = 80; addr < 84; ++addr) {
        int ret;
        uint8_t src = 0;
        // Set EEPROM address to read from
        i2c_write_blocking(i2c0, addr, &src, 1, false);
        // Try to read the EEPROM data
        ret = i2c_read_blocking(i2c0, addr, this->rawData[addr - 80], 2048, false);
        if (ret > 0) {
            this->responding[addr - 80] = true;
            if (this->rawData[addr - 80][0] == 0xff) {
                // EEPROM detected but content (boardType) invalid => yellow LED
                statusLeds.setStatic(addr - 80, 1, 1, 0);
            } else {
                // EEPROM detected and content seems valid => green LED
                statusLeds.setStatic(addr - 80, 0, 1, 0);
            }
        } else {
            // EEPROM not detected :(
                statusLeds.setStatic(addr - 80, 1, 0, 0);
        }
    }
    statusLeds.writeLeds();
}

void BoardConfig::prepareConfig() {
    configData[0] = (ConfigData*)this->rawData[0];
    configData[1] = (ConfigData*)this->rawData[1];
    configData[2] = (ConfigData*)this->rawData[2];
    configData[3] = (ConfigData*)this->rawData[3];
    configData[4] = (ConfigData*)this->rawData[4];

    // Also copy the data from the internal flash to RAM so it can be modified
    memcpy(this->rawData[4], config_flash_contents, 2048);

    // Check if any board is connected and has a valid config
    // All IO boards in order, followed by baseboard
    bool foundConfig = false;
    for (int i = 0; i < 5; i++) {
        if (
            (configData[i]->boardType > BoardType::invalid_00) &&
            (configData[i]->boardType < BoardType::invalid_ff) &&
            (configData[i]->configVersion == CONFIG_VERSION)
        ) {
            BoardConfig::activeConfig = configData[i];
            BoardConfig::configSource = (ConfigSource)i;
            statusLeds.setStatic(i, 0, 0, 1);
            foundConfig = true;
            break;
        }
    }
    createdDefaultConfig = false;
    if (!foundConfig) {
        // We don't have any valid configuration at all :-O
        // Create a default one and use it for now
        // Since we don't know the nature of the IO boards, we save that
        // default config in the slot of the base board!
        *configData[4] = this->defaultConfig();
        createdDefaultConfig = true;
        BoardConfig::activeConfig = configData[4];
        BoardConfig::configSource = ConfigSource::Fallback;
        statusLeds.setStatic(4, 1, 0, 1);
    }
    statusLeds.setBrightness(activeConfig->statusLedBrightness);
    statusLeds.writeLeds();
}
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

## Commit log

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2021-02-23 Update pico-build.yml
    Actions: Use the hopefully correct repo specifier for the pico-sdk
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2021-05-02 Proper gcc 10 fix: Move global data to main.c and declare them with extern keyword where required
    [main.cpp]
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2021-05-04 Fix some more header includes and write some note regarding fallback config
    [main.cpp]
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2021-05-08 Fix compiler warning by removing pointer arithmetic
    [boardconfig.cpp]
2021-05-09 Remove hostMask from config, no longer use ssiTags in WebServer, Enable fetching the IP configuration from the webserver
    [boardconfig.cpp, boardconfig.h]
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2021-05-19 Fail faster if no rf24-module is connected
    [wireless.cpp]
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2021-06-12 Remove heatshrink library, use snappy instead
2021-06-13 Use snappy compression for wireless spectrum as well. Mostly to prove it's actually working and decompressable in the browser. It is :)
    [main.cpp]
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2021-07-06 Make local DMX TX work. Not correct content yet ;)
    [localdmx.cpp]
2021-07-06 Enable local output of the correct data. And introduce logging. In some form
    [localdmx.cpp]
2021-07-07 Add some more TODOs and fix reading an un-initialized variable
    [localdmx.cpp]
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2021-07-11 Make the simple Console work and look nice. Add bootstrap icons. Also fix a bug in local DMX generation
    [localdmx.cpp]
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2021-07-19 Remove workaround used for RX demo
    [wireless.cpp]
2021-07-26 Codespell: Fix two typos
    [boardconfig.cpp, wireless.cpp]
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2021-07-28 Fix wireless TX (wrong buffer was sent)
    [wireless.cpp]
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2021-08-01 Make board init considerably faster, drop the USB_QUEUE experiment again and make sending in broadcast mode fail faster in case no one is listening
    [boardconfig.cpp, main.cpp, wireless.cpp]
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2021-08-09 Wireless: Skip any actions if there is no dongle connected
    [wireless.cpp]
2021-09-28 Fix some fields in the ArtPollReply and fix typos
    [wireless.cpp]
2021-09-29 Multicore, part 2 (working fine this time): Move wireless cyclic task from core0 to core1 and introduce a mutex to the logging (buffer) code to avoid dead-locks there
    [main.cpp]
2021-09-29 Protect the logBuffer even more so the dongle doesn't crash when the log buffer is requested via web
    [wireless.cpp]
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2021-10-02 Wireless sender: Use a new tmpBuf to copy away the data so it won't change while compressing or sending
    [wireless.cpp]
2021-10-06 Simplify stdio_usb.c so it doesn't have it's own interrupt-based loop calling tud_task since we call it in our main loop anyways
2021-10-06 Fix some severe data limiting coding errors + one typo
    [localdmx.cpp]
2021-10-06 Wireless: More strict input sanitization to avoid crash by integer underflow and following out-of-bounds writing
    [wireless.cpp]
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2021-10-08 Honestly too much for one commit but here we go: - StatusLeds: New methods to turn on and single colors and add blinking mechanism. Adapt all users - StatusLeds: Add new cyclicTask method to implemen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
    [boardconfig.cpp, boardconfig.h, main.cpp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]
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2021-10-12 Use new EDP code for sending in wireless.cpp and fix the bugs it had ;)
    [wireless.cpp]
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2021-10-18 Remove no longer needed protocol data types in wireless.h since it has all been moved to edp
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2021-10-27 Try the enumFactory preprocessor solution so we have enum-to-string and string-to-enum conversions without too much effort or having to keep the data twice and in sync
    [boardconfig.cpp, boardconfig.h]
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2021-11-01 Fix writing the config to the base board's flash
    [boardconfig.cpp, main.cpp]
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2021-11-09 WebUI: Redesign HOME page and add buttons to save configuration to the different boards and to enable and disable the slots
    [main.cpp]
2021-11-16 WebUI: Properly initialize BoardStatus' tooltips and fix class name of StatusLeds
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2021-11-20 Updates to fix compilation against pico-sdk 1.3.0
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2021-11-20 Fix broken pico-sdk clone of last commit
2021-11-21 WebUI: Fix some react runtime-errors and start the Wireless page
2021-11-21 WebUI: Fix modals on config page hiding on click (bootstrap bug?) and have current value in input fields
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2021-11-26 WebUI: Show stats on Wireless page and automatically open the correct section depending on current radio role
2021-11-26 Reset default radio role to sniffer, channel 42 and HIGH txPower (instead of max)
    [boardconfig.h]
2021-12-22 WiP: hardware. Contains hardcoded paths ...
    [baseboard 4 slots.kicad_pcb, baseboard 4 slots.sch, ioboard 4ports cheap.kicad_pcb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]
2021-12-22 Add non-finished 4ports isolated IO board
    [ioboard 4ports isolated.kicad_pcb, ioboard 4ports isolated.sch]
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2021-12-22 Baseboard: Add some capacitors between GND and supply lines (nRF24 connector, RPi Pico, status LEDs and IO connectors)
    [baseboard 4slots.kicad_pcb, baseboard 4slots.sch]
2021-12-22 Fix IO connector labelling
    [baseboard 4slots.kicad_pcb]
2021-12-22 Finish ioboard 4ports isolated
    [ioboard 4ports isolated.kicad_pcb, ioboard 4ports isolated.sch]
2021-12-22 Hardware: Several fixes and improvements in schematics and PCBs (more capacitors, alternative footprint for DC/DC converter, more GND stitching, better trace placement, ...)
    [baseboard 4slots.kicad_pcb, baseboard 4slots.sch, ioboard 4ports isolated.kicad_pcb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]
2021-12-22 Silk screen and GND plane improvements
    [baseboard 4slots.kicad_pcb]
2021-12-22 Add LCSC part numbers to the schematic for production :)
    [baseboard 4slots.kicad_pcb, baseboard 4slots.sch, ioboard 4ports isolated.kicad_pcb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]
2021-12-22 Re-work ioboard 4ports cheap. Should be production-ready
    [ioboard 4ports cheap.kicad_pcb, ioboard 4ports cheap.sch]
2021-12-22 Add ioboard 2ports rdm
    [ioboard 2ports rdm.kicad_pcb, ioboard 2ports rdm.sch]
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2021-12-22 No-change commit to trigger Kicad workflow
    [baseboard 4slots.kicad_pcb]
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2021-12-22 Kicad actions: Remove spaces from folder names.... I thought we were so over that ...
    [baseboard_4slots.kicad_pcb, baseboard_4slots.sch]
2021-12-22 Move ioboard 2ports rdm -> ioboard_2ports_rdm_isolated
    [ioboard_2ports_rdm_isolated.kicad_pcb, ioboard_2ports_rdm_isolated.sch]
2021-12-22 Move ioboard 4ports cheap -> ioboard_4ports_unisolated
    [ioboard_4ports_unisolated.kicad_pcb, ioboard_4ports_unisolated.sch]
2021-12-22 Move ioboard 4ports isolated -> ioboard_4ports_isolated
    [ioboard_4ports_isolated.kicad_pcb, ioboard_4ports_isolated.sch]
2021-12-22 Add ioboard_2ports_rdm_unisolated schematic and board
    [ioboard_2ports_unisolated.kicad_pcb, ioboard_2ports_unisolated.sch]
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2021-12-22 Unify board naming and bump all to rev 0.2
    [ioboard_2ports_rdm_isolated.kicad_pcb, ioboard_2ports_rdm_isolated.sch, ioboard_2ports_unisolated.kicad_pcb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]
2021-12-22 Try adding an ERC error filter
2021-12-22 ioboard_2ports_rdm_unisolated: Use AMS1117 LDO instead of the more exotic XC6206. Bump to Rev 0.3
    [ioboard_2ports_unisolated.kicad_pcb, ioboard_2ports_unisolated.sch]
2021-12-22 Refine placement of one capacitor
    [ioboard_2ports_unisolated.kicad_pcb]
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2022-11-06 Hardware: Make the reference path to the library relative and save the files with the new kicad version
    [baseboard_4slots.kicad_pcb, baseboard_4slots.kicad_sch, baseboard_4slots.sch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]
2022-11-07 Hardware: Remove two more unneeded files
    [ioboard_2ports_unisolated.sch]
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2022-11-07 More files cleaned up + Some work on baseboard
    [baseboard_4slots.kicad_pcb, baseboard_4slots.kicad_sch]
2022-11-09 Fix gitignore Move NC3FD-H.pretty footprint library to a common location and update references Rework ioboard_2ports_rdm_isolated
    [ioboard_2ports_rdm_isolated.kicad_pcb, ioboard_2ports_rdm_isolated.kicad_sch]
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2022-11-09 Some more work on the baseboard
    [baseboard_4slots.kicad_pcb, baseboard_4slots.kicad_sch]
2022-11-13 Add I2C expansion connectors and a Grove connector for the status LEDs
    [baseboard_4slots.kicad_pcb, baseboard_4slots.kicad_sch]
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2022-11-14 Exclude two ERC errors in order for kibot to work
    [baseboard_4slots.kicad_sch]
2022-11-14 Hardware: move some capacitors around to fix the DRC errors
    [baseboard_4slots.kicad_pcb]
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2022-11-14 Baseboard: Add W5500 Mini (WIZ850io) module. Needs verification
    [baseboard_4slots.kicad_pcb, baseboard_4slots.kicad_sch]
2022-11-14 Connect the nRF24 to the now shared IRQ line and supress some ERC errors
    [baseboard_4slots.kicad_pcb, baseboard_4slots.kicad_sch]
2022-11-15 Update W5500_Mini footprint and minor fixes on the baseboard
    [baseboard_4slots.kicad_pcb, baseboard_4slots.kicad_sch]
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2022-11-15 Ignore some more ERC and DRC errors
    [ioboard_2ports_rdm_isolated.kicad_pcb, ioboard_2ports_rdm_isolated.kicad_sch, ioboard_2ports_unisolated.kicad_pcb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]
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2022-11-15 Fix two real DRC issues on baseboard
    [baseboard_4slots.kicad_pcb]
2022-11-27 Add a crude baseboard with only 2 slots
    [baseboard_2slots.kicad_pcb, baseboard_2slots.kicad_sch]
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2022-11-27 Remove unconnected labels in schematic
    [baseboard_2slots.kicad_sch]
2022-11-27 Fix DRC errors
    [baseboard_2slots.kicad_pcb]
2022-11-28 Add a IRQ config jumper for the nRF24 and the Wiz modules
    [baseboard_2slots.kicad_pcb, baseboard_2slots.kicad_sch]
2022-11-29 Add an RJ45 connector to ioboard_2ports_rdm_isolated
    [ioboard_2ports_rdm_isolated.kicad_pcb, ioboard_2ports_rdm_isolated.kicad_sch]
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2022-11-29 Replace Amphenol's RJ45 by the one by Sparkfun/4UCON
    [ioboard_2ports_rdm_isolated.kicad_pcb, ioboard_2ports_rdm_isolated.kicad_sch]
2022-11-30 Add RJ45 jacks to ioboard_2ports_rdm_unisolated as well
    [ioboard_2ports_unisolated.kicad_pcb, ioboard_2ports_unisolated.kicad_sch]
2022-11-30 Add RJ45 jack to ioboard_4ports_isolated as well
    [ioboard_4ports_isolated.kicad_pcb, ioboard_4ports_isolated.kicad_sch]
2022-11-30 Add RJ45 jack to ioboard_4ports_unisolated as well
    [ioboard_4ports_unisolated.kicad_pcb, ioboard_4ports_unisolated.kicad_sch]
2022-11-30 Bump all boards to rev 0.6
    [baseboard_2slots.kicad_pcb, baseboard_2slots.kicad_sch, baseboard_4slots.kicad_pcb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]
2022-11-30 Fix DRC
    [ioboard_4ports_isolated.kicad_pcb]
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2022-12-02 Hardware: Add missing LCSC references for some caps
    [baseboard_2slots.kicad_sch, baseboard_4slots.kicad_sch]
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2023-01-22 Several smaller fixes and additions
    [boardconfig.cpp, main.cpp]
2023-01-23 Hardware: Baseboard 4 slots: Don't let W5500 and nRF24 share the IRQ line, add a solder jumper instead
    [baseboard_4slots.kicad_pcb, baseboard_4slots.kicad_sch]
2023-01-23 Fix chart.js-related build error and wireless spectrum chart size
2023-01-29 Hardware: Fix one IC order code (was 2kbit EEPROM instead of 64kbit ....)
    [ioboard_2ports_rdm_isolated.kicad_pcb, ioboard_2ports_rdm_isolated.kicad_sch]
2023-01-29 New config format designed for 2048 byte flash & EEPROMs. Not everything correctly updated but it compiles for now
    [boardconfig.cpp, boardconfig.h]
2023-01-29 Config size fixes and some more info via the web server
    [boardconfig.cpp, boardconfig.h]
2023-01-30 Fix reading the config from flash
    [boardconfig.cpp]
2023-01-31 Fixes (EDP patching, config save and load) and re-order webserver's overview a little
    [boardconfig.cpp, boardconfig.h, wireless.cpp]
2023-01-31 Fix compilation with PICO_BOARD=pico_w by making some stuff optional
    [main.cpp, pins.h]
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2023-02-01 Fix compilation for non-Pico-W boards
    [main.cpp]
2023-02-01 Re-fix build for pico and pico_w
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2023-02-10 Revert 4f3e76310f3861f8f7e384d4e3e6091997211c83 since we build fixed for Pico-W now
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2023-02-14 Fix a minor typo
    [boardconfig.h]
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2024-11-03 Update baseboards to KiCad 8, add copper keepout underneath Picos, add OpenHardware logo
    [baseboard_2slots.kicad_pcb, baseboard_2slots.kicad_sch, baseboard_4slots.kicad_pcb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]
2024-11-03 Update ioboards to KiCad 8, add OpenHardware logo
    [ioboard_2ports_rdm_isolated.kicad_pcb, ioboard_2ports_rdm_isolated.kicad_sch, ioboard_2ports_unisolated.kicad_pcb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]
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2024-11-03 Fix/Exclude ERC and DRC errors on baseboards
    [baseboard_2slots.kicad_pcb, baseboard_4slots.kicad_pcb]
2024-11-03 Fix/Exclude ERC and DRC errors on ioboards
    [ioboard_2ports_rdm_isolated.kicad_sch, ioboard_2ports_unisolated.kicad_pcb, ioboard_2ports_unisolated.kicad_sch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]
2024-11-03 Update all footprints and ignore all other DRC warning on baseboards
    [baseboard_2slots.kicad_pcb, baseboard_4slots.kicad_pcb]
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2024-11-03 Update all footprints and ignore all other DRC warning on ioboards
    [ioboard_2ports_rdm_isolated.kicad_pcb, ioboard_2ports_rdm_isolated.kicad_sch, ioboard_2ports_unisolated.kicad_pcb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]
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
